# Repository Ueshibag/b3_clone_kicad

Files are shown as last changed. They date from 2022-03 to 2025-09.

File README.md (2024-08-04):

# B3 clone KiCad projects, symbols and footprints libraries

## drawbars

A set of 4 interconnected PCBs controlling 38 potentiometers. The left most PCB houses
an Arduino Nano Every which analog to digital converters are used to collect drawbars
positions and send the corresponding MIDI messages to the B3 emulator software (setBfree) running on a Raspberry Pi.

## keyboards

Scans both Fatar keyboards and sends MIDI messages to setBfree

## percussions_expr_pedal

Scans the percussion control switches and performs analog to digital conversion for the
expression pedal. Signals are routed towards the vibrato_chorus_leslie PCB.

## rpi_extension

This is merely a connection PCB for other boards to connect to the Raspberry PI.

## vibrato_chorus_leslie

Scans the vibrato and chorus switches as well as the Leslie 3-position switch (stop/slow/fast).
Gathers signals from the percussions_expr_pedal PCB. Houses an Arduino Nano Every which sends
MIDI messages to setBfree.

## vibrato_chorus_rotary_switch

A small PCB on which the 6-position rotary switch is soldered. This PCB is connected to the
vibrato_chorus_leslie board.

## volume_reverb_overdrive

This board houses three rotary encoders to control IQaudio PiDAC+ volume, setBfree reverb and overdrive. The overdrive rotary switch embeds a push button to safely power down the Raspberry PI.

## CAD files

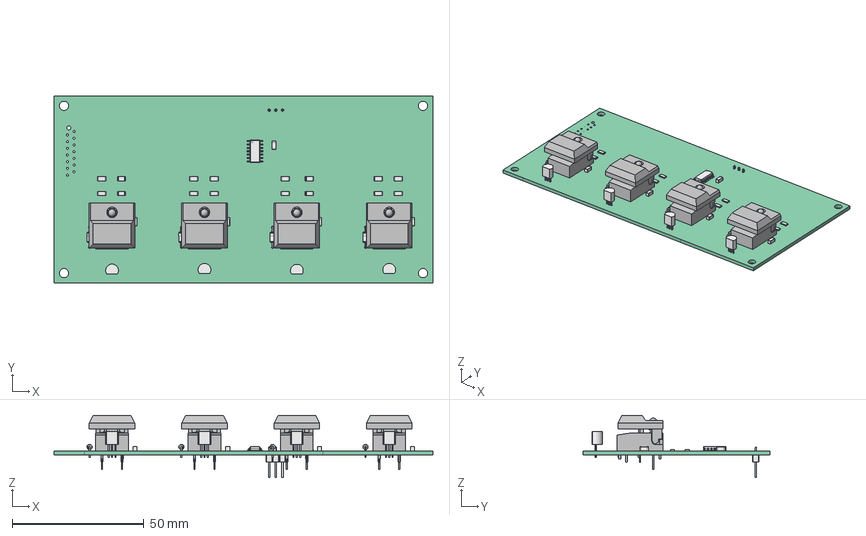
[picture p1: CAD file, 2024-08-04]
percussions_expr_pedal/percussions_expr_pedal.FCStd
143.7 x 71.0 x 23.6 mm
Pcb_b367
R14_R_1206_3216Metric_5984d3bbee4c x 16
C4_C_1206_3216Metric_f569d871501b x 5
Q4_TO-92_Inline_Narrow_949824a83cfa x 4
D3_D_DO-35_SOD27_P7.62mm_Horizontal_7e08c083b87b x 4
U1_SOIC_14_39x87mm_P127mm_67988bc3ad81
J2_PinHeader_1x03_P254mm_Vertical_995c9cfdbebc

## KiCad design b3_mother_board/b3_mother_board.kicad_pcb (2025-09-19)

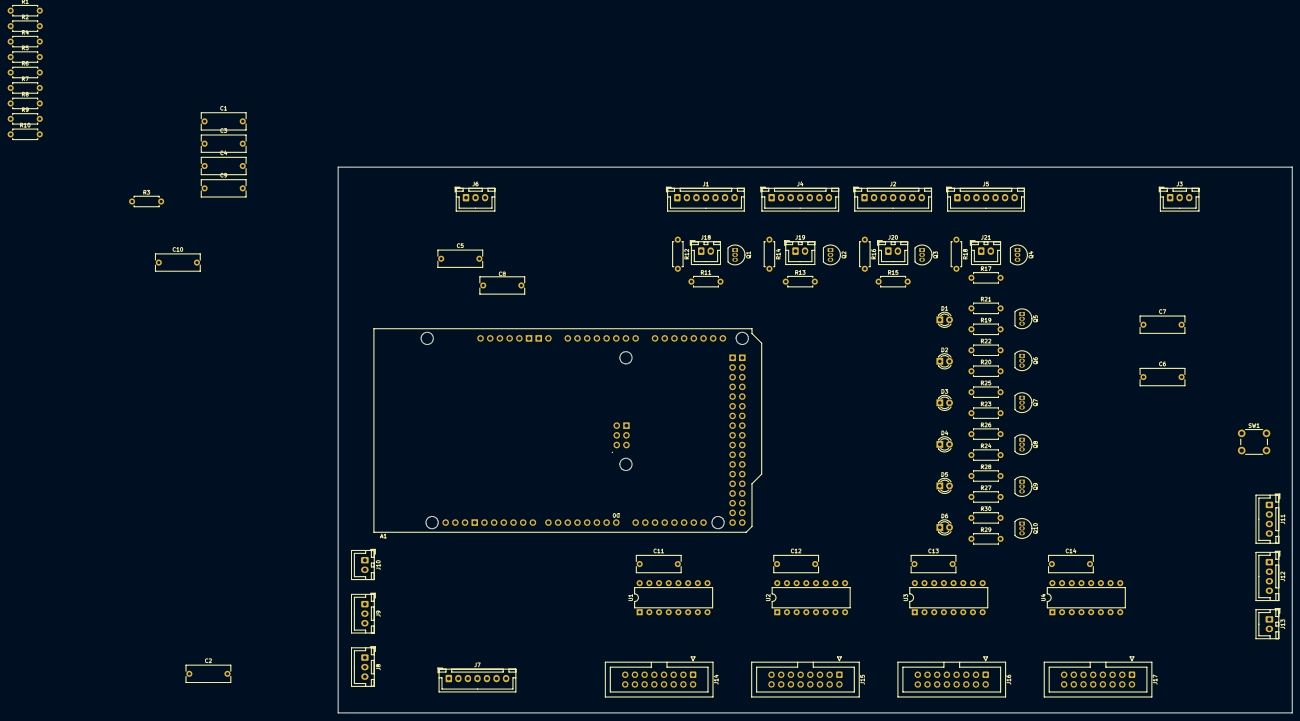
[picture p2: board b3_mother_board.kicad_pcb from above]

Board: 2 copper layers, 250.0 x 143.0 mm, 87 parts (1 on the bottom side), 127 nets, no tracks yet.

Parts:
A1: Arduino_Mega2560_R3_Shield
C1, C2, C3, C4, C5, C6, C7, C8, C9, C10, C11, C12, C13, C14: 100n; C_Rect_L11.5mm_W4.3mm_P10.00mm_MKT
D1: Keyboards; LED_D3.0mm
D2: Vib/Chr; LED_D3.0mm
D3: Drawbars; LED_D3.0mm
D4: Percussions; LED_D3.0mm
D5: Leslie; LED_D3.0mm
D6: Expression Ped.; LED_D3.0mm
J1: Drawbars_1; JST_XH_B7B-XH-A_1x07_P2.50mm_Vertical
J2: Drawbars_3; JST_XH_B7B-XH-A_1x07_P2.50mm_Vertical
J3: Expression Pedal; JST_XH_B3B-XH-A_1x03_P2.50mm_Vertical
J4: Drawbars_2; JST_XH_B7B-XH-A_1x07_P2.50mm_Vertical
J5: Drawbars_4; JST_XH_B7B-XH-A_1x07_P2.50mm_Vertical
J6: Leslie; JST_XH_B3B-XH-A_1x03_P2.50mm_Vertical
J7: V/C Rotary Knob; JST_XH_B7B-XH-A_1x07_P2.50mm_Vertical
J8: Ovrdrv/Vib LEDs; JST_XH_B3B-XH-A_1x03_P2.50mm_Vertical
J9: Ovrdrv/Vib Switches; JST_XH_B3B-XH-A_1x03_P2.50mm_Vertical
J10: Ovrdrv/Vib PWR; JST_XH_B2B-XH-A_1x02_P2.50mm_Vertical
J11: Percussion LEDs; JST_XH_B4B-XH-A_1x04_P2.50mm_Vertical
J12: Percussion Switches; JST_XH_B4B-XH-A_1x04_P2.50mm_Vertical
J13: Percussion PWR; JST_XH_B2B-XH-A_1x02_P2.50mm_Vertical
J14: Upper Keyboard Left; IDC-Header_2x08_P2.54mm_Vertical
J15: Upper Keyboard Right; IDC-Header_2x08_P2.54mm_Vertical
J16: Lower Keyboard Left; IDC-Header_2x08_P2.54mm_Vertical
J17: Lower Keyboard Right; IDC-Header_2x08_P2.54mm_Vertical
J18: Upper A LED; JST_XH_B2B-XH-A_1x02_P2.50mm_Vertical
J19: Upper B LED; JST_XH_B2B-XH-A_1x02_P2.50mm_Vertical
J20: Lower A LED; JST_XH_B2B-XH-A_1x02_P2.50mm_Vertical
J21: Lower B LED; JST_XH_B2B-XH-A_1x02_P2.50mm_Vertical
Q1, Q2, Q3, Q4, Q5, Q6, Q7, Q8, Q9, Q10: BC547; TO-92_Inline
R1, R2: 68K; R_Axial_DIN0207_L6.3mm_D2.5mm_P7.62mm_Horizontal
R3, R4, R5, R6: 2.2K; R_Axial_DIN0207_L6.3mm_D2.5mm_P7.62mm_Horizontal
R7, R8, R9, R10: 100; R_Axial_DIN0207_L6.3mm_D2.5mm_P7.62mm_Horizontal
R11, R13, R15, R17, R19, R20, R23, R24, R27, R29: 2.8K; R_Axial_DIN0207_L6.3mm_D2.5mm_P7.62mm_Horizontal
R12, R14, R16, R18, R21, R22, R25, R26, R28, R30: 220; R_Axial_DIN0207_L6.3mm_D2.5mm_P7.62mm_Horizontal
SW1: Reset; SW_PUSH_6mm_H4.3mm
U1, U2, U3, U4: 4051; DIP-16_W7.62mm

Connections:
+5V: A1.5V1 (5V), A1.5V2 (SPI_5V), A1.5V3 (5V), A1.5V4 (5V), A1.AREF, C11.1, C12.1, C13.1, C14.1, J1.1, J2.1, J3.1, J4.1, J5.1, J6.1, J10.1, J13.1, R1.1, R12.1, R14.1, R16.1, R18.1, R21.1, R22.1, R25.1, R26.1, R28.1, R30.1, U1.16 (VDD), U2.16 (VDD), U3.16 (VDD), U4.16 (VDD)
/C1: A1.D42, J7.2
/C2: A1.D44, J7.4
/C3: A1.D46, J7.6
/DB_A1_ANLG: A1.A0, C1.1, J1.2
/DB_A2_ANLG: A1.A2, C5.1, J4.2
/DB_A3_ANLG: A1.A4, C2.1, J2.2
/DB_A4_ANLG: A1.A6, C6.1, J5.2
/DB_B1_ANLG: A1.A1, C3.1, J1.3
/DB_B2_ANLG: A1.A3, C7.1, J4.3
/DB_B3_ANLG: A1.A5, C4.1, J2.3
/DB_B4_ANLG: A1.A7, C8.1, J5.3
/DB_MUX_A: A1.D47, J1.4, J2.4, J4.4, J5.4
/DB_MUX_B: A1.D48, J1.5, J2.5, J4.5, J5.5
/DB_MUX_C: A1.D49, J1.6, J2.6, J4.6, J5.6
/DWB_LED: A1.D1 (D1/TX0), R23.1
/EXPR_PEDAL_ANLG: A1.A8, C9.1, J3.2
/EXP_LED: A1.D16 (D16/TX2), R29.1
/KBD_LED: A1.D0 (D0/RX0), R19.1
/LESLIE_ANLG: A1.A9, C10.1, J6.2, R1.2, R2.1
/LO_A_LED: A1.D52 (D52_SCK), R15.1
/LO_B_LED: A1.D53 (D53_CS), R17.1
/LSL_LED: A1.D17 (D17/RX2), R27.1
/OVERDRIVE_LED: A1.D30, J8.1
/OVERDRIVE_SWITCH: A1.D27, J9.1
/PERC_DELAY_LED: A1.D39, J11.3
/PERC_DELAY_SWITCH: A1.D35, J12.3
/PERC_HARMONIC_LED: A1.D40, J11.4
/PERC_HARMONIC_SWITCH: A1.D36, J12.4
/PERC_ON_OFF_LED: A1.D37, J11.1
/PERC_ON_OFF_SWITCH: A1.D33, J12.1
/PERC_VOLUME_LED: A1.D38, J11.2
/PERC_VOLUME_SWITCH: A1.D34, J12.2
/PRC_LED: A1.D18 (D18/TX1), R24.1
/T0: A1.D11, J14.2, J15.2, J16.2, J17.2
/T1: A1.D12, J14.4, J15.4, J16.4, J17.4
/T2: A1.D13, J14.6, J15.6, J16.6, J17.6
/T3: A1.D22, J14.8, J15.8, J16.8, J17.8
/T4: A1.D23, J14.10, J15.10, J16.10, J17.10
/T5: A1.D24, J14.12, J15.12, J16.12, J17.12
/T6: A1.D25, J14.14, J15.14, J16.14, J17.14
/T7: A1.D26, J14.16, J15.16, J16.16, J17.16
/UP_A_LED: A1.D50 (D50_MISO), R11.1
/UP_B_LED: A1.D51 (D51_MOSI), R13.1
/V1: A1.D41, J7.1
/V2: A1.D43, J7.3
/V3: A1.D45, J7.5
/VIBRATO_LOWER_LED: A1.D32, J8.3
/VIBRATO_LOWER_SWITCH: A1.D29, J9.3
/VIBRATO_UPPER_LED: A1.D31, J8.2
/VIBRATO_UPPER_SWITCH: A1.D28, J9.2
/VIB_LED: A1.D19 (D19/RX1), R20.1
/keyboards_control_sub/BRA: A1.D7, R7.1
/keyboards_control_sub/BRA0: J14.3, U1.13 (X0)
/keyboards_control_sub/BRA1: J14.7, U1.14 (X1)
/keyboards_control_sub/BRA2: J14.11, U1.15 (X2)
/keyboards_control_sub/BRA3: J14.15, U1.12 (X3)
/keyboards_control_sub/BRA4: J15.3, U1.1 (X4)
/keyboards_control_sub/BRA5: J15.7, U1.5 (X5)
/keyboards_control_sub/BRA6: J15.11, U1.2 (X6)
/keyboards_control_sub/BRA7: J15.15, U1.4 (X7)
/keyboards_control_sub/BRB: A1.D8, R8.1
/keyboards_control_sub/BRB0: J16.3, U3.13 (X0)
/keyboards_control_sub/BRB1: J16.7, U3.14 (X1)
/keyboards_control_sub/BRB2: J16.11, U3.15 (X2)
/keyboards_control_sub/BRB3: J16.15, U3.12 (X3)
/keyboards_control_sub/BRB4: J17.3, U3.1 (X4)
/keyboards_control_sub/BRB5: J17.7, U3.5 (X5)
/keyboards_control_sub/BRB6: J17.11, U3.2 (X6)
/keyboards_control_sub/BRB7: J17.15, U3.4 (X7)
/keyboards_control_sub/KB_MUX_A: A1.D4, U1.11 (A), U2.11 (A), U3.11 (A), U4.11 (A)
/keyboards_control_sub/KB_MUX_B: A1.D5, U1.10 (B), U2.10 (B), U3.10 (B), U4.10 (B)
/keyboards_control_sub/KB_MUX_C: A1.D6, U1.9 (C), U2.9 (C), U3.9 (C), U4.9 (C)
/keyboards_control_sub/MKA: A1.D9, R9.1
/keyboards_control_sub/MKA0: J14.1, U2.13 (X0)
/keyboards_control_sub/MKA1: J14.5, U2.14 (X1)
/keyboards_control_sub/MKA2: J14.9, U2.15 (X2)
/keyboards_control_sub/MKA3: J14.13, U2.12 (X3)
/keyboards_control_sub/MKA4: J15.1, U2.1 (X4)
/keyboards_control_sub/MKA5: J15.5, U2.5 (X5)
/keyboards_control_sub/MKA6: J15.9, U2.2 (X6)
/keyboards_control_sub/MKA7: J15.13, U2.4 (X7)
/keyboards_control_sub/MKB: A1.D10, R10.1
/keyboards_control_sub/MKB0: J16.1, U4.13 (X0)
/keyboards_control_sub/MKB1: J16.5, U4.14 (X1)
/keyboards_control_sub/MKB2: J16.9, U4.15 (X2)
/keyboards_control_sub/MKB3: J16.13, U4.12 (X3)
/keyboards_control_sub/MKB4: J17.1, U4.1 (X4)
/keyboards_control_sub/MKB5: J17.5, U4.5 (X5)
/keyboards_control_sub/MKB6: J17.9, U4.2 (X6)
/keyboards_control_sub/MKB7: J17.13, U4.4 (X7)
GND: A1.GND1 (GND), A1.GND2 (GND), A1.GND3 (GND), A1.GND4 (SPI_GND), A1.GND5 (GND), A1.GND6 (GND), C1.2, C2.2, C3.2, C4.2, C5.2, C6.2, C7.2, C8.2, C9.2, C10.2, C11.2, C12.2, C13.2, C14.2, J1.7, J2.7, J3.3, J4.7, J5.7, J6.3, J7.7, J10.2, J13.2, Q1.3 (E), Q2.3 (E), Q3.3 (E), Q4.3 (E), Q5.3 (E), Q6.3 (E), Q7.3 (E), Q8.3 (E), Q9.3 (E), Q10.3 (E), R2.2, R3.2, R4.2, R5.2, R6.2, SW1.1, U1.6 (Inh), U1.7 (VEE), U1.8 (VSS), U2.6 (Inh), U2.7 (VEE), U2.8 (VSS), U3.6 (Inh), U3.7 (VEE), U3.8 (VSS), U4.6 (Inh), U4.7 (VEE), U4.8 (VSS)
unnamed: A1.RST1 (RESET), SW1.2
unnamed: D1.2 (A), R21.2
unnamed: D1.1 (K), Q5.1 (C)
unnamed: D2.2 (A), R22.2
unnamed: D2.1 (K), Q6.1 (C)
unnamed: D3.2 (A), R25.2
unnamed: D3.1 (K), Q7.1 (C)
unnamed: D4.2 (A), R26.2
unnamed: D4.1 (K), Q8.1 (C)
unnamed: D5.2 (A), R28.2
unnamed: D5.1 (K), Q9.1 (C)
unnamed: D6.2 (A), R30.2
unnamed: D6.1 (K), Q10.1 (C)
unnamed: J18.1, R12.2
unnamed: J18.2, Q1.1 (C)
unnamed: J19.1, R14.2
unnamed: J19.2, Q2.1 (C)
unnamed: J20.1, R16.2
unnamed: J20.2, Q3.1 (C)
unnamed: J21.1, R18.2
unnamed: J21.2, Q4.1 (C)
unnamed: Q1.2 (B), R11.2
unnamed: Q2.2 (B), R13.2
unnamed: Q3.2 (B), R15.2
unnamed: Q4.2 (B), R17.2
unnamed: Q5.2 (B), R19.2
unnamed: Q6.2 (B), R20.2
unnamed: Q7.2 (B), R23.2
unnamed: Q8.2 (B), R24.2
unnamed: Q9.2 (B), R27.2
unnamed: Q10.2 (B), R29.2
unnamed: R3.1, R7.2, U1.3 (X)
unnamed: R4.1, R9.2, U2.3 (X)
unnamed: R5.1, R8.2, U3.3 (X)
unnamed: R6.1, R10.2, U4.3 (X)

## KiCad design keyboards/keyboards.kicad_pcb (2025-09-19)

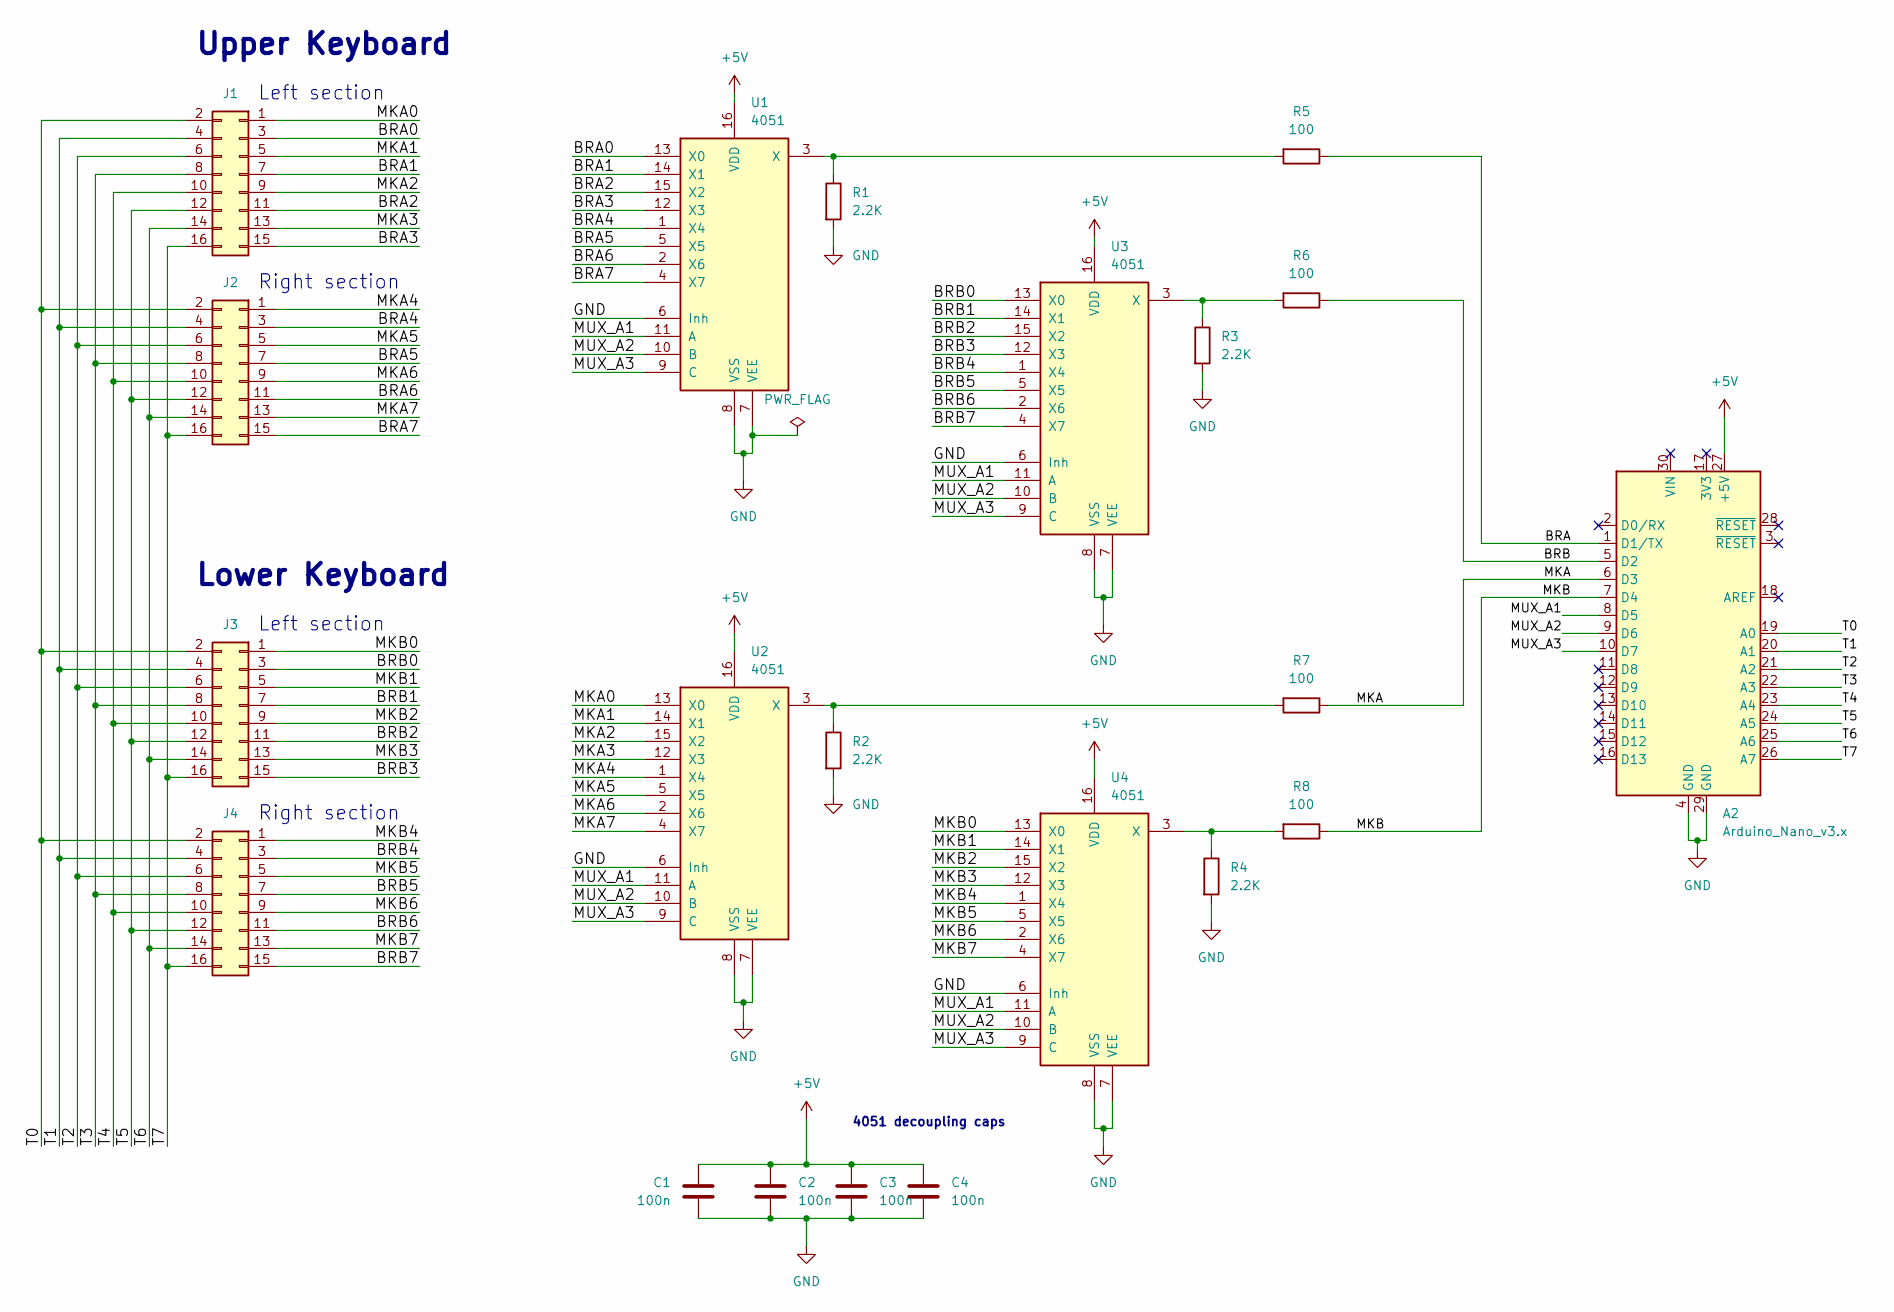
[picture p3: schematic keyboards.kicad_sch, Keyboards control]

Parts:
A2: Arduino_Nano_v3.x; Arduino_Nano
C1, C2, C3, C4: 100n; C_1206_3216Metric_Pad1.33x1.80mm_HandSolder
J1, J2, J3, J4: Conn_02x08_Odd_Even; IDC-Header_2x08_P2.54mm_Vertical
R1, R2, R3, R4: 2.2K; R_1206_3216Metric_Pad1.30x1.75mm_HandSolder
R5, R6, R7, R8: 100; R_1206_3216Metric_Pad1.30x1.75mm_HandSolder
U1, U2, U3, U4: 4051; DIP-16_W7.62mm

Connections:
+5V: A2.27 (+5V), C1.1, C2.1, C3.1, C4.1, U1.16 (VDD), U2.16 (VDD), U3.16 (VDD), U4.16 (VDD)
/BRA: A2.1 (D1/TX), R5.1
/BRA0: J1.3, U1.13 (X0)
/BRA1: J1.7, U1.14 (X1)
/BRA2: J1.11, U1.15 (X2)
/BRA3: J1.15, U1.12 (X3)
/BRA4: J2.3, U1.1 (X4)
/BRA5: J2.7, U1.5 (X5)
/BRA6: J2.11, U1.2 (X6)
/BRA7: J2.15, U1.4 (X7)
/BRB: A2.5 (D2), R6.1
/BRB0: J3.3, U3.13 (X0)
/BRB1: J3.7, U3.14 (X1)
/BRB2: J3.11, U3.15 (X2)
/BRB3: J3.15, U3.12 (X3)
/BRB4: J4.3, U3.1 (X4)
/BRB5: J4.7, U3.5 (X5)
/BRB6: J4.11, U3.2 (X6)
/BRB7: J4.15, U3.4 (X7)
/MKA: A2.6 (D3), R7.1
/MKA0: J1.1, U2.13 (X0)
/MKA1: J1.5, U2.14 (X1)
/MKA2: J1.9, U2.15 (X2)
/MKA3: J1.13, U2.12 (X3)
/MKA4: J2.1, U2.1 (X4)
/MKA5: J2.5, U2.5 (X5)
/MKA6: J2.9, U2.2 (X6)
/MKA7: J2.13, U2.4 (X7)
/MKB: A2.7 (D4), R8.1
/MKB0: J3.1, U4.13 (X0)
/MKB1: J3.5, U4.14 (X1)
/MKB2: J3.9, U4.15 (X2)
/MKB3: J3.13, U4.12 (X3)
/MKB4: J4.1, U4.1 (X4)
/MKB5: J4.5, U4.5 (X5)
/MKB6: J4.9, U4.2 (X6)
/MKB7: J4.13, U4.4 (X7)
/MUX_A1: A2.8 (D5), U1.11 (A), U2.11 (A), U3.11 (A), U4.11 (A)
/MUX_A2: A2.9 (D6), U1.10 (B), U2.10 (B), U3.10 (B), U4.10 (B)
/MUX_A3: A2.10 (D7), U1.9 (C), U2.9 (C), U3.9 (C), U4.9 (C)
/T0: A2.19 (A0), J1.2, J2.2, J3.2, J4.2
/T1: A2.20 (A1), J1.4, J2.4, J3.4, J4.4
/T2: A2.21 (A2), J1.6, J2.6, J3.6, J4.6
/T3: A2.22 (A3), J1.8, J2.8, J3.8, J4.8
/T4: A2.23 (A4), J1.10, J2.10, J3.10, J4.10
/T5: A2.24 (A5), J1.12, J2.12, J3.12, J4.12
/T6: A2.25 (A6), J1.14, J2.14, J3.14, J4.14
/T7: A2.26 (A7), J1.16, J2.16, J3.16, J4.16
GND: A2.4 (GND), A2.29 (GND), C1.2, C2.2, C3.2, C4.2, R1.2, R2.2, R3.2, R4.2, U1.6 (Inh), U1.7 (VEE), U1.8 (VSS), U2.6 (Inh), U2.7 (VEE), U2.8 (VSS), U3.6 (Inh), U3.7 (VEE), U3.8 (VSS), U4.6 (Inh), U4.7 (VEE), U4.8 (VSS)
unnamed: R1.1, R5.2, U1.3 (X)
unnamed: R2.1, R7.2, U2.3 (X)
unnamed: R3.1, R6.2, U3.3 (X)
unnamed: R4.1, R8.2, U4.3 (X)

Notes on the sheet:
Left section
Lower Keyboard
4051 decoupling caps
Upper Keyboard
Right section

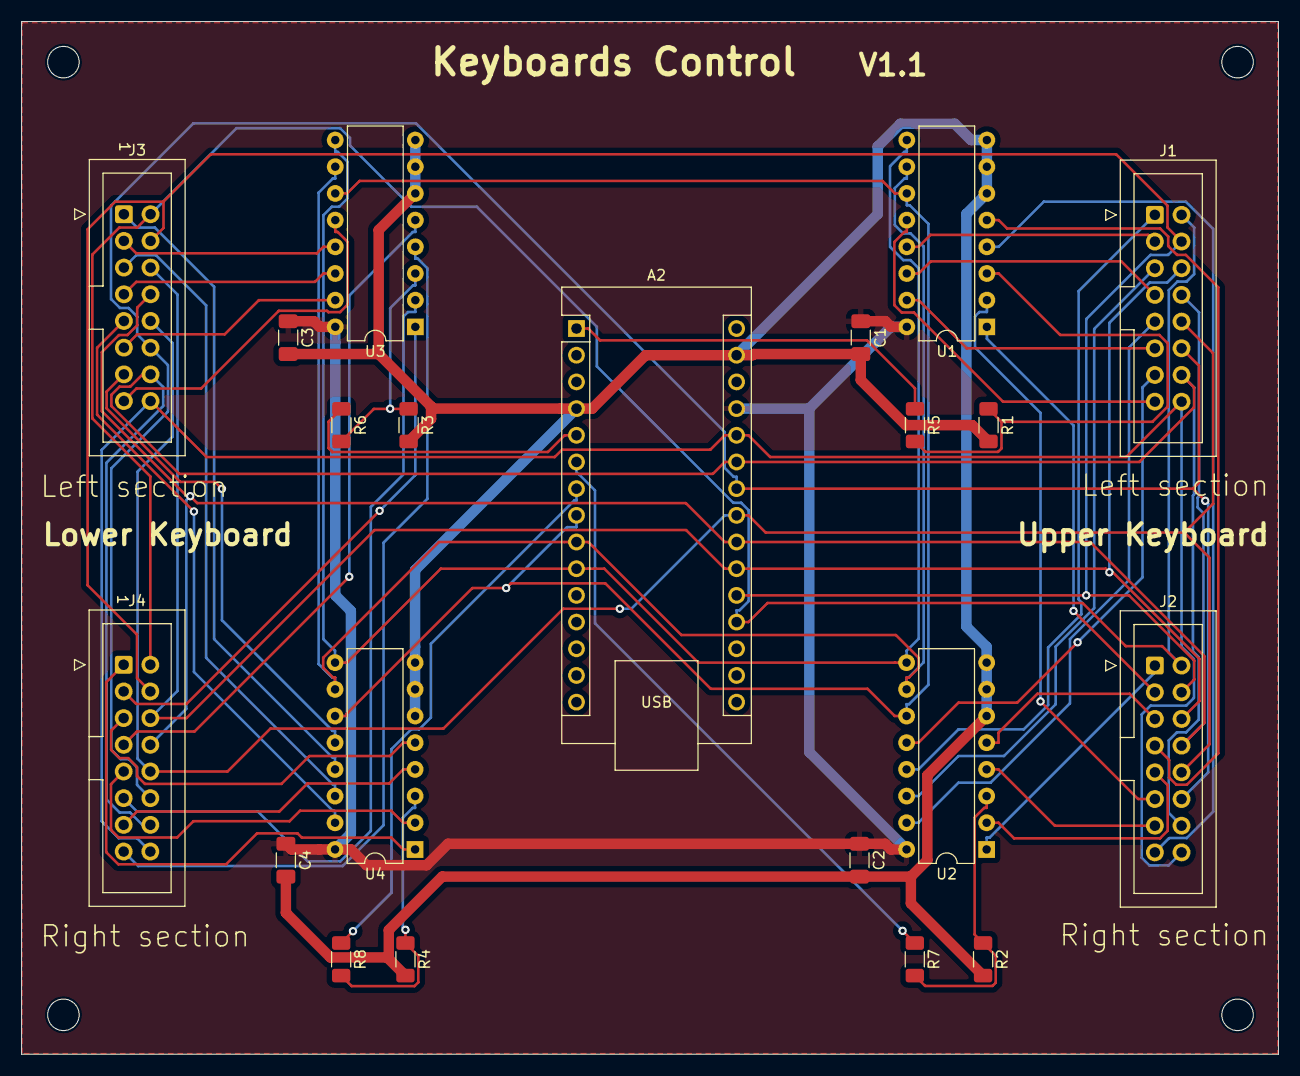
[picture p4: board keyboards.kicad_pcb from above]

Board: 2 copper layers, 119.6 x 98.3 mm, 25 parts (0 on the bottom side), 53 nets.

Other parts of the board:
REF1, REF2, REF3, REF4: MountingHole_3mm

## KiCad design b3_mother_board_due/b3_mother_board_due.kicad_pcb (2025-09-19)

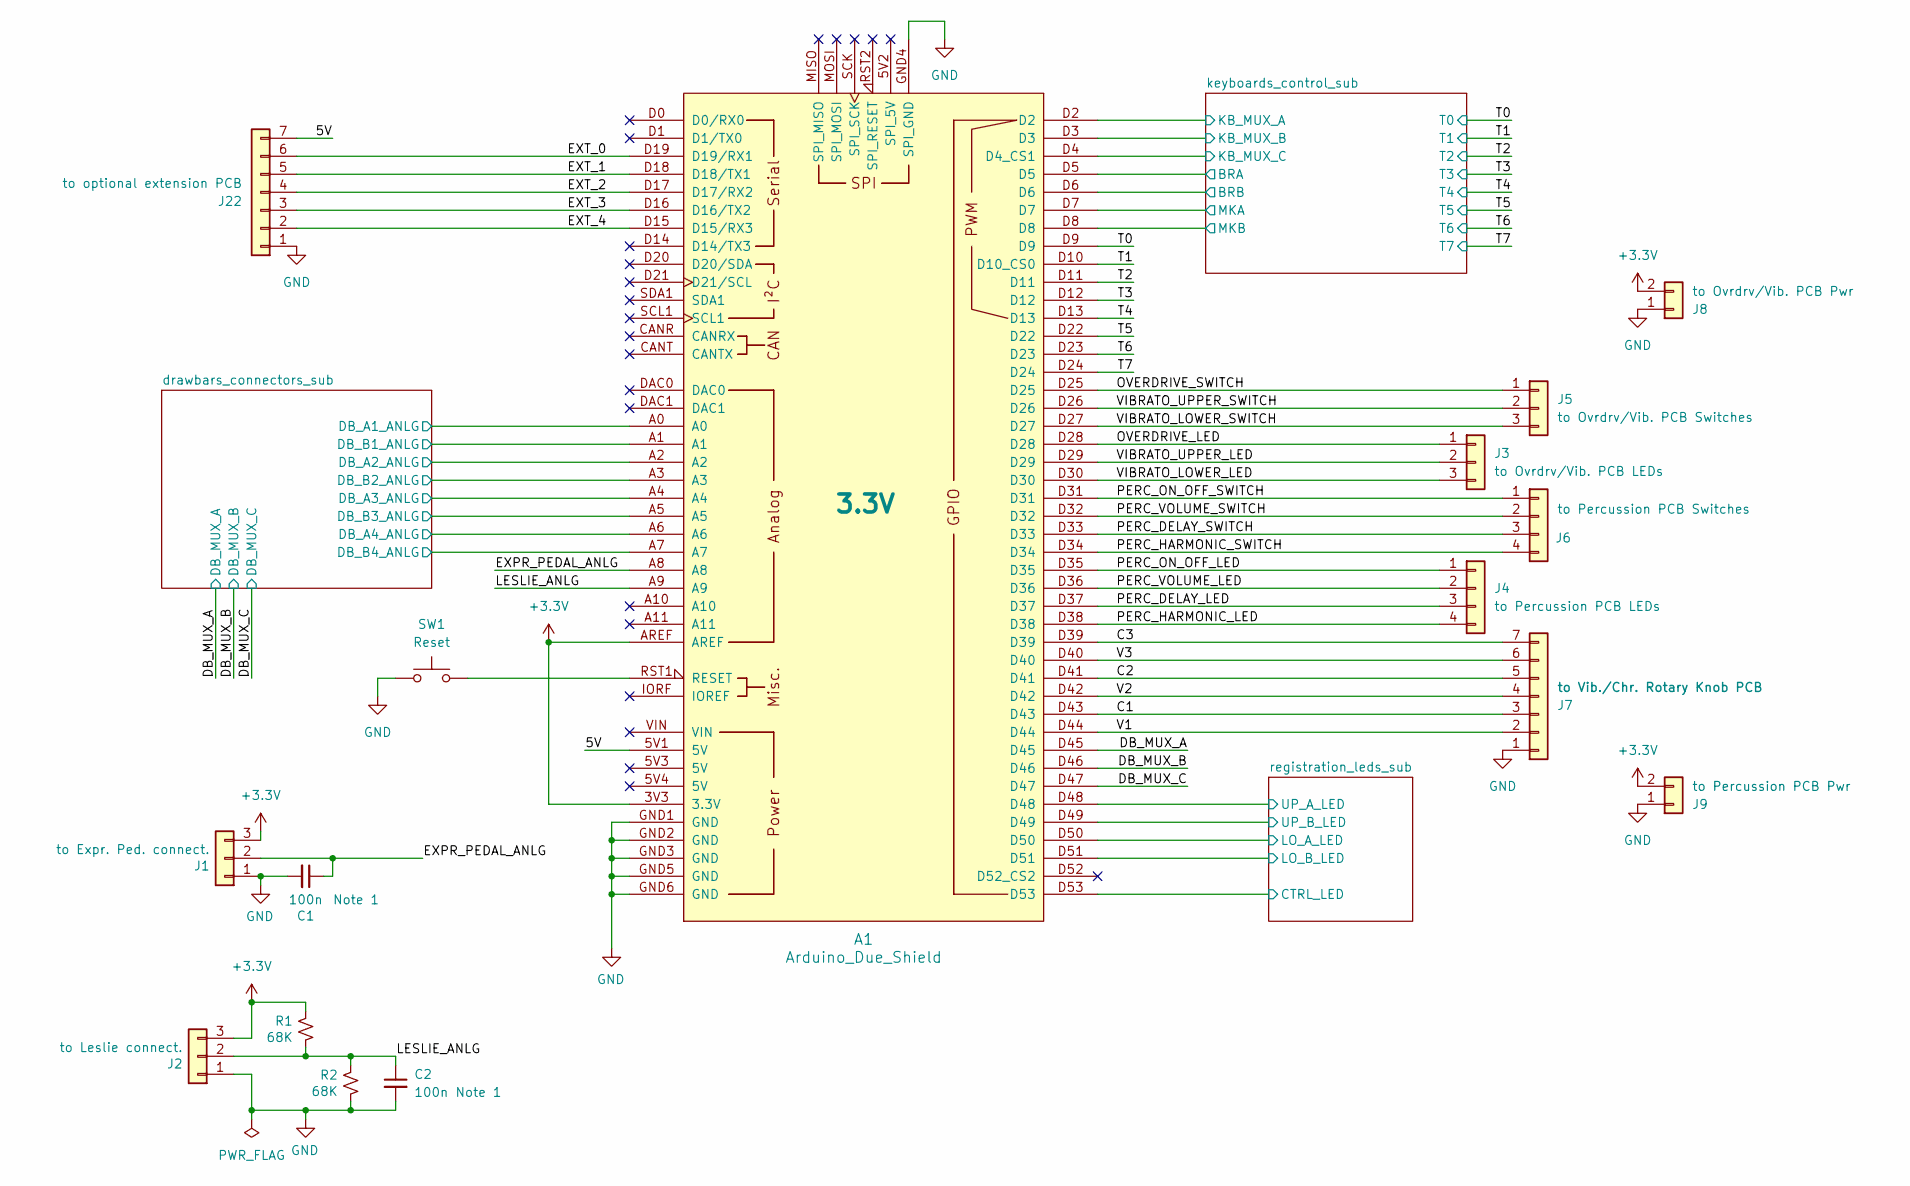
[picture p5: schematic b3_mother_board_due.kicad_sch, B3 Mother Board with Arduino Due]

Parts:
A1: Arduino_Due_Shield; Voltage 3.3V
C1, C2: 100n; C_Rect_L11.5mm_W4.3mm_P10.00mm_MKT
J1: to Expr. Ped. connect.; JST_XH_B3B-XH-A_1x03_P2.50mm_Vertical
J2: to Leslie connect.; JST_XH_B3B-XH-A_1x03_P2.50mm_Vertical
J3: to Ovrdrv/Vib. PCB LEDs; JST_XH_B3B-XH-A_1x03_P2.50mm_Vertical
J4: to Percussion PCB LEDs; JST_XH_B4B-XH-A_1x04_P2.50mm_Vertical
J5: to Ovrdrv/Vib. PCB Switches; JST_XH_B3B-XH-A_1x03_P2.50mm_Vertical
J6: to Percussion PCB Switches; JST_XH_B4B-XH-A_1x04_P2.50mm_Vertical
J7: to Vib./Chr. Rotary Knob PCB; JST_XH_B7B-XH-A_1x07_P2.50mm_Vertical
J8: to Ovrdrv/Vib. PCB Pwr; JST_XH_B2B-XH-A_1x02_P2.50mm_Vertical
J9: to Percussion PCB Pwr; JST_XH_B2B-XH-A_1x02_P2.50mm_Vertical
J22: to optional extension PCB; JST_XH_B7B-XH-A_1x07_P2.50mm_Vertical
R1, R2: 68K; R_Axial_DIN0207_L6.3mm_D2.5mm_P7.62mm_Horizontal
SW1: Reset; SW_PUSH_6mm_H4.3mm

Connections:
+3.3V: A1.3V3 (3.3V), A1.AREF, J1.3, J2.3, J8.2, J9.2, R1.1; also elsewhere on the board
/5V: A1.5V1 (5V), J22.7
/C1: A1.D43, J7.3
/C2: A1.D41, J7.5
/C3: A1.D39, J7.7
/DB_MUX_A: A1.D45; also elsewhere on the board
/DB_MUX_B: A1.D46; also elsewhere on the board
/DB_MUX_C: A1.D47; also elsewhere on the board
/EXPR_PEDAL_ANLG: A1.A8, C1.1, J1.2
/EXT_0: A1.D19 (D19/RX1), J22.6
/EXT_1: A1.D18 (D18/TX1), J22.5
/EXT_2: A1.D17 (D17/RX2), J22.4
/EXT_3: A1.D16 (D16/TX2), J22.3
/EXT_4: A1.D15 (D15/RX3), J22.2
/LESLIE_ANLG: A1.A9, C2.1, J2.2, R1.2, R2.1
/OVERDRIVE_LED: A1.D28, J3.1
/OVERDRIVE_SWITCH: A1.D25, J5.1
/PERC_DELAY_LED: A1.D37, J4.3
/PERC_DELAY_SWITCH: A1.D33, J6.3
/PERC_HARMONIC_LED: A1.D38, J4.4
/PERC_HARMONIC_SWITCH: A1.D34, J6.4
/PERC_ON_OFF_LED: A1.D35, J4.1
/PERC_ON_OFF_SWITCH: A1.D31, J6.1
/PERC_VOLUME_LED: A1.D36, J4.2
/PERC_VOLUME_SWITCH: A1.D32, J6.2
/T0: A1.D9; also elsewhere on the board
/T1: A1.D10 (D10_CS0); also elsewhere on the board
/T2: A1.D11; also elsewhere on the board
/T3: A1.D12; also elsewhere on the board
/T4: A1.D13; also elsewhere on the board
/T5: A1.D22; also elsewhere on the board
/T6: A1.D23; also elsewhere on the board
/T7: A1.D24; also elsewhere on the board
/V1: A1.D44, J7.2
/V2: A1.D42, J7.4
/V3: A1.D40, J7.6
/VIBRATO_LOWER_LED: A1.D30, J3.3
/VIBRATO_LOWER_SWITCH: A1.D27, J5.3
/VIBRATO_UPPER_LED: A1.D29, J3.2
/VIBRATO_UPPER_SWITCH: A1.D26, J5.2
/drawbars_connectors_sub/DB_A1_ANLG: A1.A0; also elsewhere on the board
/drawbars_connectors_sub/DB_A2_ANLG: A1.A2; also elsewhere on the board
/drawbars_connectors_sub/DB_A3_ANLG: A1.A4; also elsewhere on the board
/drawbars_connectors_sub/DB_A4_ANLG: A1.A6; also elsewhere on the board
/drawbars_connectors_sub/DB_B1_ANLG: A1.A1; also elsewhere on the board
/drawbars_connectors_sub/DB_B2_ANLG: A1.A3; also elsewhere on the board
/drawbars_connectors_sub/DB_B3_ANLG: A1.A5; also elsewhere on the board
/drawbars_connectors_sub/DB_B4_ANLG: A1.A7; also elsewhere on the board
/keyboards_control_sub/BRA: A1.D5; also elsewhere on the board
/keyboards_control_sub/BRB: A1.D6; also elsewhere on the board
/keyboards_control_sub/KB_MUX_A: A1.D2; also elsewhere on the board
/keyboards_control_sub/KB_MUX_B: A1.D3; also elsewhere on the board
/keyboards_control_sub/KB_MUX_C: A1.D4 (D4_CS1); also elsewhere on the board
/keyboards_control_sub/MKA: A1.D7; also elsewhere on the board
/keyboards_control_sub/MKB: A1.D8; also elsewhere on the board
/registration_leds_sub/CTRL_LED: A1.D53; also elsewhere on the board
/registration_leds_sub/LO_A_LED: A1.D50; also elsewhere on the board
/registration_leds_sub/LO_B_LED: A1.D51; also elsewhere on the board
/registration_leds_sub/UP_A_LED: A1.D48; also elsewhere on the board
/registration_leds_sub/UP_B_LED: A1.D49; also elsewhere on the board
GND: A1.GND1 (GND), A1.GND2 (GND), A1.GND3 (GND), A1.GND4 (SPI_GND), A1.GND5 (GND), A1.GND6 (GND), C1.2, C2.2, J1.1, J2.1, J7.1, J8.1, J9.1, J22.1, R2.2, SW1.1; also elsewhere on the board
unnamed: A1.RST1 (RESET), SW1.2

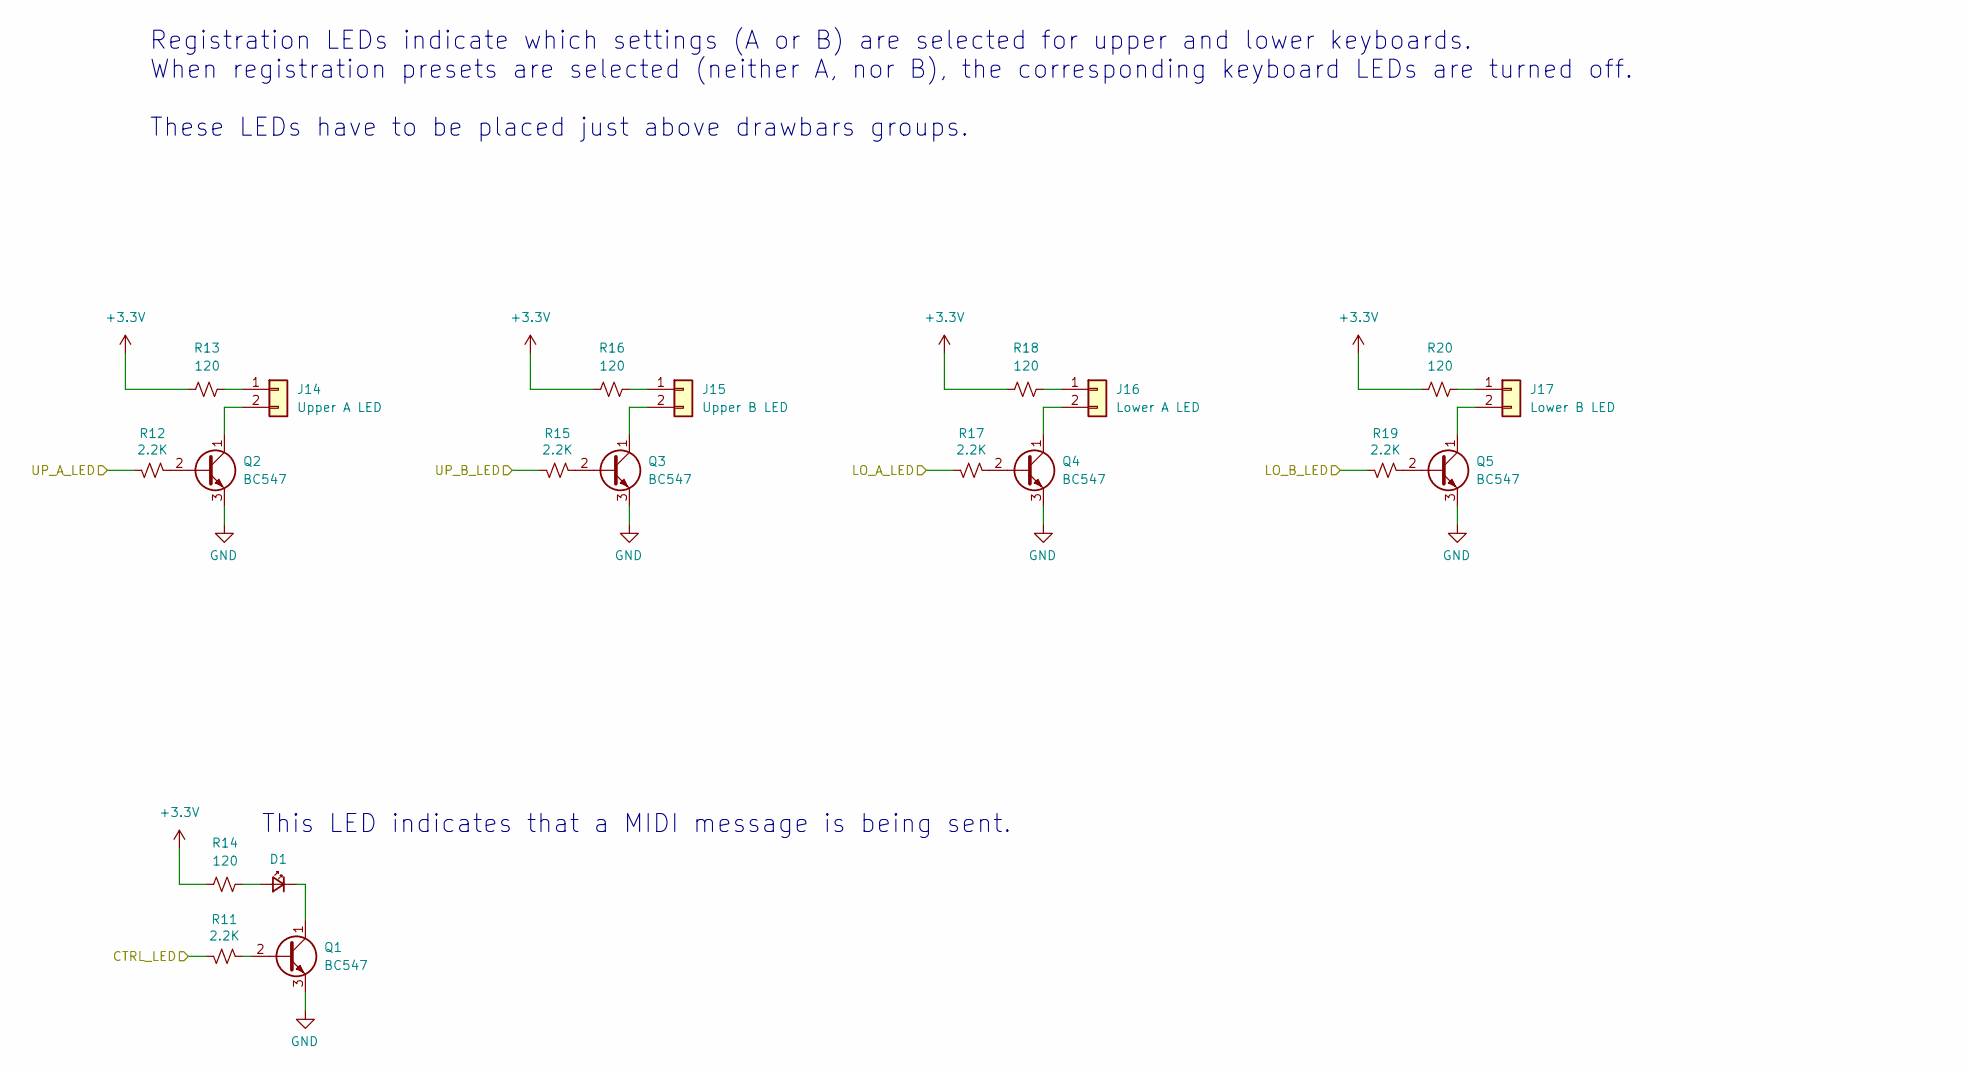
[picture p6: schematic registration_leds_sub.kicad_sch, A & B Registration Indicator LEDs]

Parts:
D1: Keyboards; LED_D3.0mm
J14: Upper A LED; JST_XH_B2B-XH-A_1x02_P2.50mm_Vertical
J15: Upper B LED; JST_XH_B2B-XH-A_1x02_P2.50mm_Vertical
J16: Lower A LED; JST_XH_B2B-XH-A_1x02_P2.50mm_Vertical
J17: Lower B LED; JST_XH_B2B-XH-A_1x02_P2.50mm_Vertical
Q1, Q2, Q3, Q4, Q5: BC547; TO-92_Inline
R11, R12, R15, R17, R19: 2.2K; R_Axial_DIN0207_L6.3mm_D2.5mm_P7.62mm_Horizontal
R13, R14, R16, R18, R20: 120; R_Axial_DIN0207_L6.3mm_D2.5mm_P7.62mm_Horizontal

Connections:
+3.3V: R13.1, R14.1, R16.1, R18.1, R20.1; also elsewhere on the board
/registration_leds_sub/CTRL_LED: R11.1; also elsewhere on the board
/registration_leds_sub/LO_A_LED: R17.1; also elsewhere on the board
/registration_leds_sub/LO_B_LED: R19.1; also elsewhere on the board
/registration_leds_sub/UP_A_LED: R12.1; also elsewhere on the board
/registration_leds_sub/UP_B_LED: R15.1; also elsewhere on the board
GND: Q1.3 (E), Q2.3 (E), Q3.3 (E), Q4.3 (E), Q5.3 (E); also elsewhere on the board
unnamed: D1.2 (A), R14.2
unnamed: D1.1 (K), Q1.1 (C)
unnamed: J14.1, R13.2
unnamed: J14.2, Q2.1 (C)
unnamed: J15.1, R16.2
unnamed: J15.2, Q3.1 (C)
unnamed: J16.1, R18.2
unnamed: J16.2, Q4.1 (C)
unnamed: J17.1, R20.2
unnamed: J17.2, Q5.1 (C)
unnamed: Q1.2 (B), R11.2
unnamed: Q2.2 (B), R12.2
unnamed: Q3.2 (B), R15.2
unnamed: Q4.2 (B), R17.2
unnamed: Q5.2 (B), R19.2

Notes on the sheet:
Registration LEDs indicate which settings (A or B) are selected for upper and lower keyboards. When registration presets are selected (neither A, nor B), the corresponding keyboard LEDs are turned off. These LEDs have to be placed just above drawbars groups.
This LED indicates that a MIDI message is being sent.

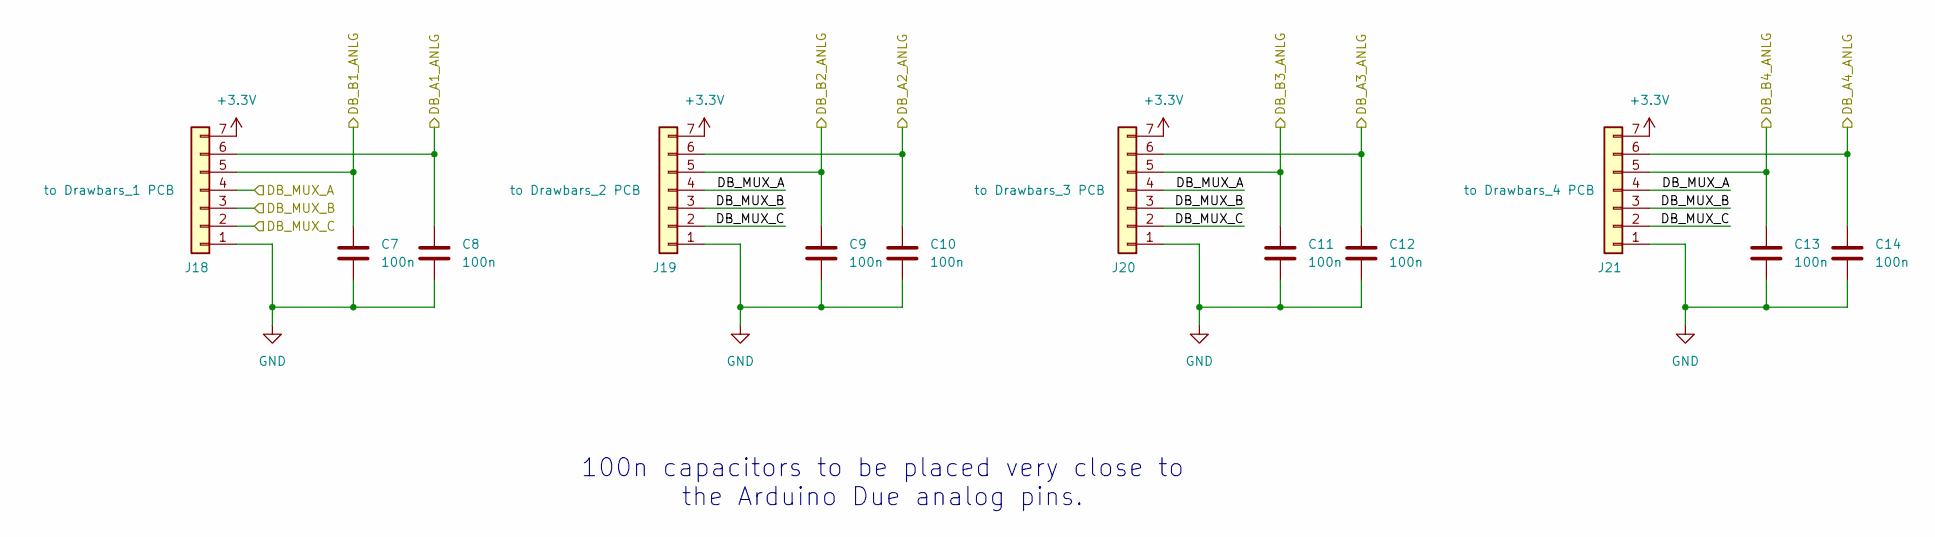
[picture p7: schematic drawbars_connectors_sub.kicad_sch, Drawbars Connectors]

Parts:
C7, C8, C9, C10, C11, C12, C13, C14: 100n; C_Rect_L11.5mm_W4.3mm_P10.00mm_MKT
J18: to Drawbars_1 PCB; JST_XH_B7B-XH-A_1x07_P2.50mm_Vertical
J19: to Drawbars_2 PCB; JST_XH_B7B-XH-A_1x07_P2.50mm_Vertical
J20: to Drawbars_3 PCB; JST_XH_B7B-XH-A_1x07_P2.50mm_Vertical
J21: to Drawbars_4 PCB; JST_XH_B7B-XH-A_1x07_P2.50mm_Vertical

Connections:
+3.3V: J18.7, J19.7, J20.7, J21.7; also elsewhere on the board
/DB_MUX_A: J18.4, J19.4, J20.4, J21.4; also elsewhere on the board
/DB_MUX_B: J18.3, J19.3, J20.3, J21.3; also elsewhere on the board
/DB_MUX_C: J18.2, J19.2, J20.2, J21.2; also elsewhere on the board
/drawbars_connectors_sub/DB_A1_ANLG: C8.1, J18.6; also elsewhere on the board
/drawbars_connectors_sub/DB_A2_ANLG: C10.1, J19.6; also elsewhere on the board
/drawbars_connectors_sub/DB_A3_ANLG: C12.1, J20.6; also elsewhere on the board
/drawbars_connectors_sub/DB_A4_ANLG: C14.1, J21.6; also elsewhere on the board
/drawbars_connectors_sub/DB_B1_ANLG: C7.1, J18.5; also elsewhere on the board
/drawbars_connectors_sub/DB_B2_ANLG: C9.1, J19.5; also elsewhere on the board
/drawbars_connectors_sub/DB_B3_ANLG: C11.1, J20.5; also elsewhere on the board
/drawbars_connectors_sub/DB_B4_ANLG: C13.1, J21.5; also elsewhere on the board
GND: C7.2, C8.2, C9.2, C10.2, C11.2, C12.2, C13.2, C14.2, J18.1, J19.1, J20.1, J21.1; also elsewhere on the board

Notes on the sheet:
100n capacitors to be placed very close to the Arduino Due analog pins.

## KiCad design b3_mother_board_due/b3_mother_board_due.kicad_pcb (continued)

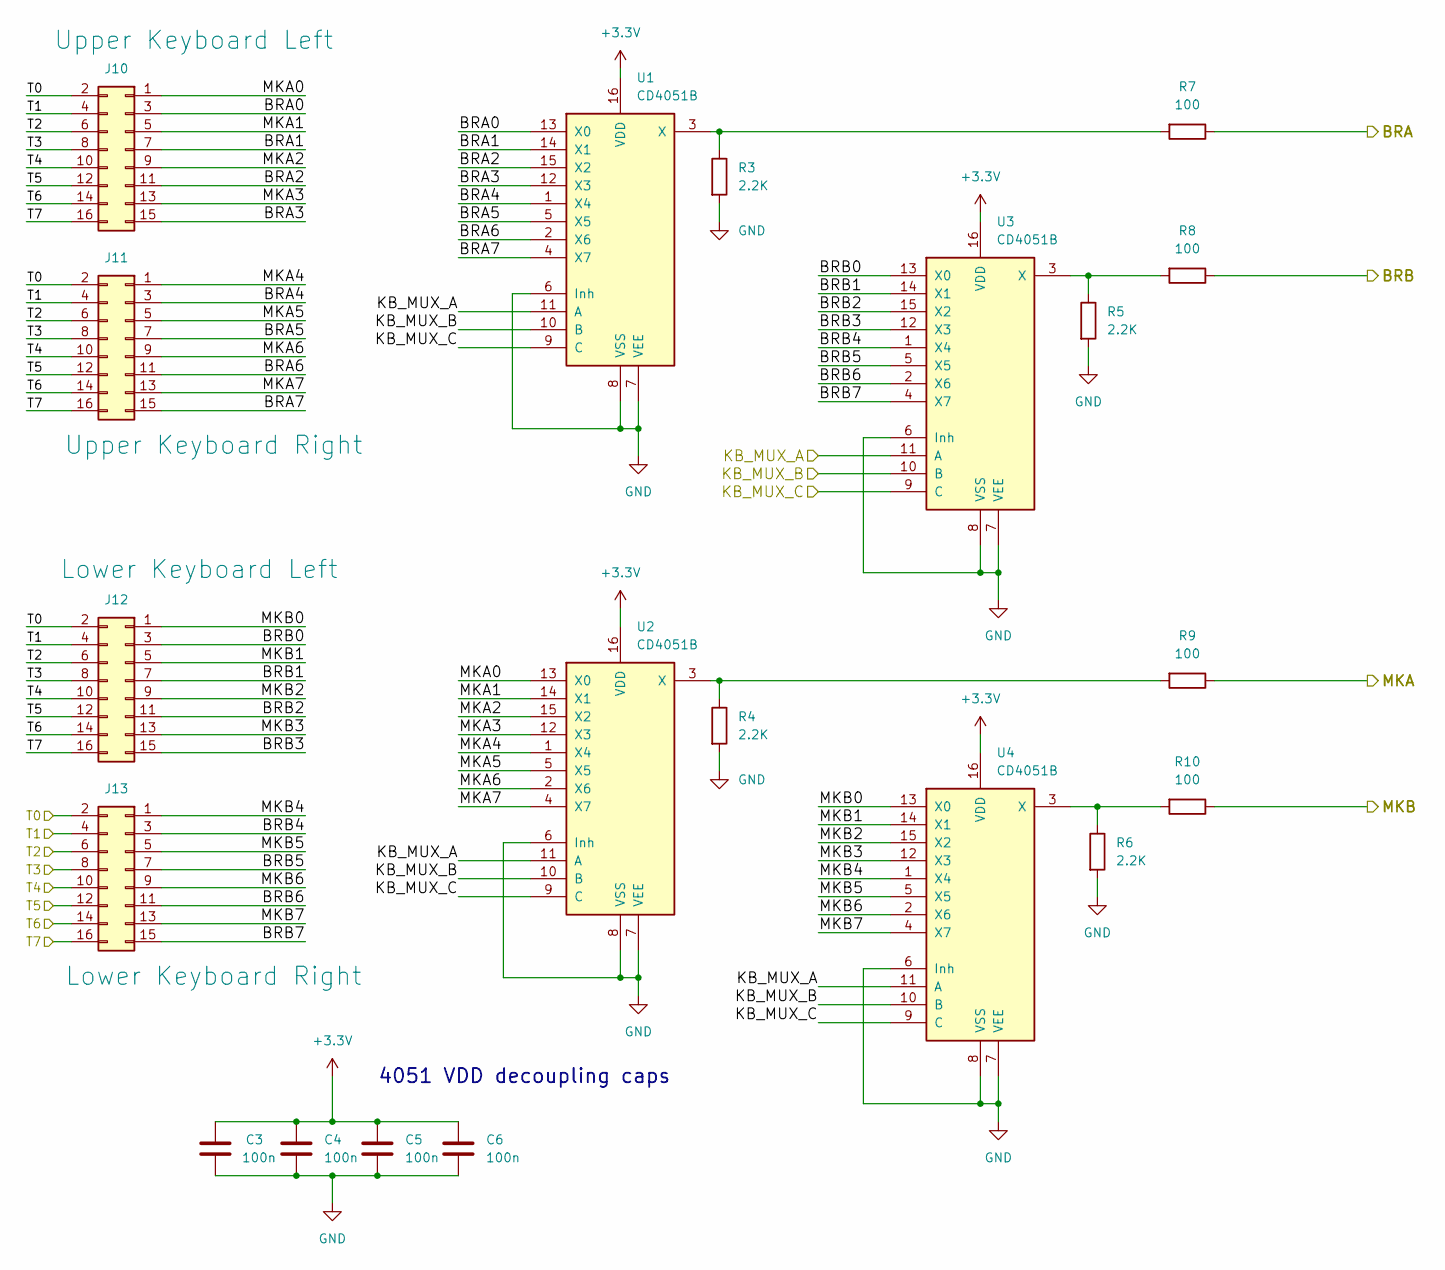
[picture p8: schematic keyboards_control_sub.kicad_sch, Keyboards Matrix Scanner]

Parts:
C3, C4, C5, C6: 100n; C_Rect_L11.5mm_W4.3mm_P10.00mm_MKT
J10: Upper Keyboard Left; IDC-Header_2x08_P2.54mm_Vertical
J11: Upper Keyboard Right; IDC-Header_2x08_P2.54mm_Vertical
J12: Lower Keyboard Left; IDC-Header_2x08_P2.54mm_Vertical
J13: Lower Keyboard Right; IDC-Header_2x08_P2.54mm_Vertical
R3, R4, R5, R6: 2.2K; R_Axial_DIN0207_L6.3mm_D2.5mm_P7.62mm_Horizontal
R7, R8, R9, R10: 100; R_Axial_DIN0207_L6.3mm_D2.5mm_P7.62mm_Horizontal
U1, U2, U3, U4: CD4051B; DIP-16_W7.62mm

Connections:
+3.3V: C3.1, C4.1, C5.1, C6.1, U1.16 (VDD), U2.16 (VDD), U3.16 (VDD), U4.16 (VDD); also elsewhere on the board
/T0: J10.2, J11.2, J12.2, J13.2; also elsewhere on the board
/T1: J10.4, J11.4, J12.4, J13.4; also elsewhere on the board
/T2: J10.6, J11.6, J12.6, J13.6; also elsewhere on the board
/T3: J10.8, J11.8, J12.8, J13.8; also elsewhere on the board
/T4: J10.10, J11.10, J12.10, J13.10; also elsewhere on the board
/T5: J10.12, J11.12, J12.12, J13.12; also elsewhere on the board
/T6: J10.14, J11.14, J12.14, J13.14; also elsewhere on the board
/T7: J10.16, J11.16, J12.16, J13.16; also elsewhere on the board
/keyboards_control_sub/BRA: R7.1; also elsewhere on the board
/keyboards_control_sub/BRA0: J10.3, U1.13 (X0)
/keyboards_control_sub/BRA1: J10.7, U1.14 (X1)
/keyboards_control_sub/BRA2: J10.11, U1.15 (X2)
/keyboards_control_sub/BRA3: J10.15, U1.12 (X3)
/keyboards_control_sub/BRA4: J11.3, U1.1 (X4)
/keyboards_control_sub/BRA5: J11.7, U1.5 (X5)
/keyboards_control_sub/BRA6: J11.11, U1.2 (X6)
/keyboards_control_sub/BRA7: J11.15, U1.4 (X7)
/keyboards_control_sub/BRB: R8.1; also elsewhere on the board
/keyboards_control_sub/BRB0: J12.3, U3.13 (X0)
/keyboards_control_sub/BRB1: J12.7, U3.14 (X1)
/keyboards_control_sub/BRB2: J12.11, U3.15 (X2)
/keyboards_control_sub/BRB3: J12.15, U3.12 (X3)
/keyboards_control_sub/BRB4: J13.3, U3.1 (X4)
/keyboards_control_sub/BRB5: J13.7, U3.5 (X5)
/keyboards_control_sub/BRB6: J13.11, U3.2 (X6)
/keyboards_control_sub/BRB7: J13.15, U3.4 (X7)
/keyboards_control_sub/KB_MUX_A: U1.11 (A), U2.11 (A), U3.11 (A), U4.11 (A); also elsewhere on the board
/keyboards_control_sub/KB_MUX_B: U1.10 (B), U2.10 (B), U3.10 (B), U4.10 (B); also elsewhere on the board
/keyboards_control_sub/KB_MUX_C: U1.9 (C), U2.9 (C), U3.9 (C), U4.9 (C); also elsewhere on the board
/keyboards_control_sub/MKA: R9.1; also elsewhere on the board
/keyboards_control_sub/MKA0: J10.1, U2.13 (X0)
/keyboards_control_sub/MKA1: J10.5, U2.14 (X1)
/keyboards_control_sub/MKA2: J10.9, U2.15 (X2)
/keyboards_control_sub/MKA3: J10.13, U2.12 (X3)
/keyboards_control_sub/MKA4: J11.1, U2.1 (X4)
/keyboards_control_sub/MKA5: J11.5, U2.5 (X5)
/keyboards_control_sub/MKA6: J11.9, U2.2 (X6)
/keyboards_control_sub/MKA7: J11.13, U2.4 (X7)
/keyboards_control_sub/MKB: R10.1; also elsewhere on the board
/keyboards_control_sub/MKB0: J12.1, U4.13 (X0)
/keyboards_control_sub/MKB1: J12.5, U4.14 (X1)
/keyboards_control_sub/MKB2: J12.9, U4.15 (X2)
/keyboards_control_sub/MKB3: J12.13, U4.12 (X3)
/keyboards_control_sub/MKB4: J13.1, U4.1 (X4)
/keyboards_control_sub/MKB5: J13.5, U4.5 (X5)
/keyboards_control_sub/MKB6: J13.9, U4.2 (X6)
/keyboards_control_sub/MKB7: J13.13, U4.4 (X7)
GND: C3.2, C4.2, C5.2, C6.2, R3.2, R4.2, R5.2, R6.2, U1.6 (Inh), U1.7 (VEE), U1.8 (VSS), U2.6 (Inh), U2.7 (VEE), U2.8 (VSS), U3.6 (Inh), U3.7 (VEE), U3.8 (VSS), U4.6 (Inh), U4.7 (VEE), U4.8 (VSS); also elsewhere on the board
unnamed: R3.1, R7.2, U1.3 (X)
unnamed: R4.1, R9.2, U2.3 (X)
unnamed: R5.1, R8.2, U3.3 (X)
unnamed: R6.1, R10.2, U4.3 (X)

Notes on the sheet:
4051 VDD decoupling caps

Board: 2 copper layers, 68 parts (0 on the bottom side), 113 nets, no tracks yet.

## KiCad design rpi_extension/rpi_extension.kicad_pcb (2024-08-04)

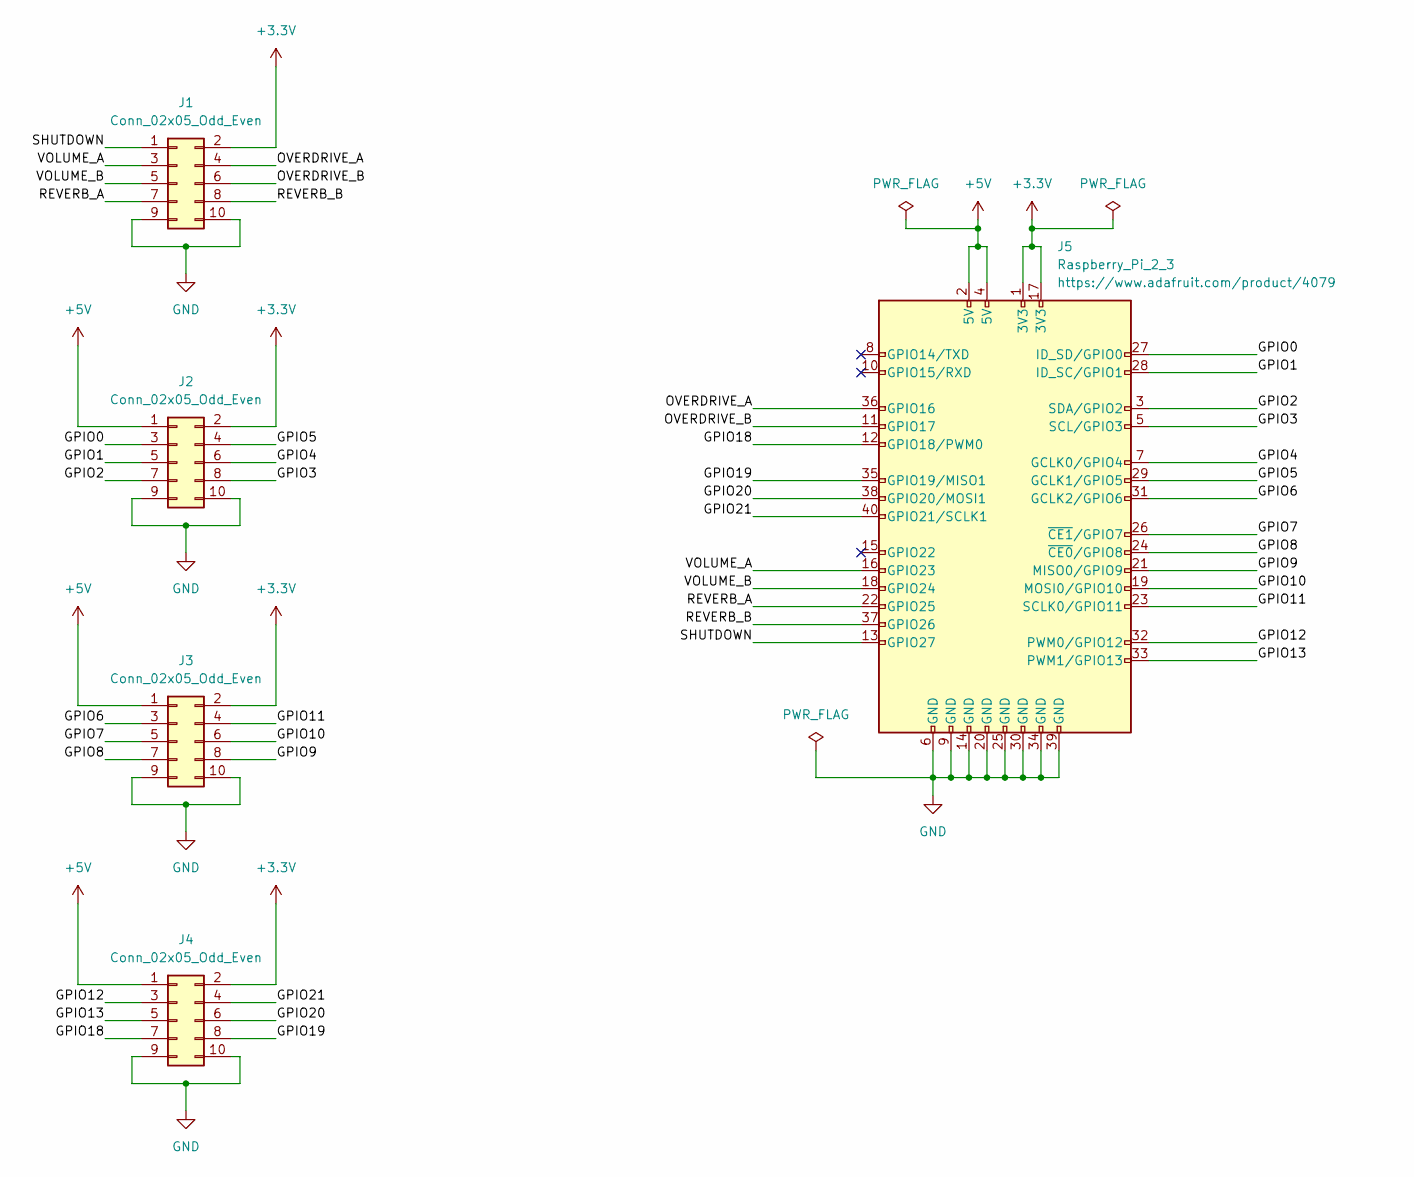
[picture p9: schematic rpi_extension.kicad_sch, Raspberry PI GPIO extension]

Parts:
J1, J2, J3, J4: Conn_02x05_Odd_Even; IDC-Header_2x05_P2.54mm_Horizontal
J5: Raspberry_Pi_2_3; PinSocket_2x20_P2.54mm_Vertical

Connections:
+3.3V: J1.2, J2.2, J3.2, J4.2, J5.1 (3V3), J5.17 (3V3)
+5V: J2.1, J3.1, J4.1, J5.2 (5V), J5.4 (5V)
/GPIO0: J2.3, J5.27 (ID_SD/GPIO0)
/GPIO1: J2.5, J5.28 (ID_SC/GPIO1)
/GPIO2: J2.7, J5.3 (SDA/GPIO2)
/GPIO3: J2.8, J5.5 (SCL/GPIO3)
/GPIO4: J2.6, J5.7 (GCLK0/GPIO4)
/GPIO5: J2.4, J5.29 (GCLK1/GPIO5)
/GPIO6: J3.3, J5.31 (GCLK2/GPIO6)
/GPIO7: J3.5, J5.26 (~CE1/GPIO7)
/GPIO8: J3.7, J5.24 (~CE0/GPIO8)
/GPIO9: J3.8, J5.21 (MISO0/GPIO9)
/GPIO10: J3.6, J5.19 (MOSI0/GPIO10)
/GPIO11: J3.4, J5.23 (SCLK0/GPIO11)
/GPIO12: J4.3, J5.32 (PWM0/GPIO12)
/GPIO13: J4.5, J5.33 (PWM1/GPIO13)
/GPIO18: J4.7, J5.12 (GPIO18/PWM0)
/GPIO19: J4.8, J5.35 (GPIO19/MISO1)
/GPIO20: J4.6, J5.38 (GPIO20/MOSI1)
/GPIO21: J4.4, J5.40 (GPIO21/SCLK1)
/OVERDRIVE_A: J1.4, J5.36 (GPIO16)
/OVERDRIVE_B: J1.6, J5.11 (GPIO17)
/REVERB_A: J1.7, J5.22 (GPIO25)
/REVERB_B: J1.8, J5.37 (GPIO26)
/SHUTDOWN: J1.1, J5.13 (GPIO27)
/VOLUME_A: J1.3, J5.16 (GPIO23)
/VOLUME_B: J1.5, J5.18 (GPIO24)
GND: J1.9, J1.10, J2.9, J2.10, J3.9, J3.10, J4.9, J4.10, J5.6 (GND), J5.9 (GND), J5.14 (GND), J5.20 (GND), J5.25 (GND), J5.30 (GND), J5.34 (GND), J5.39 (GND)

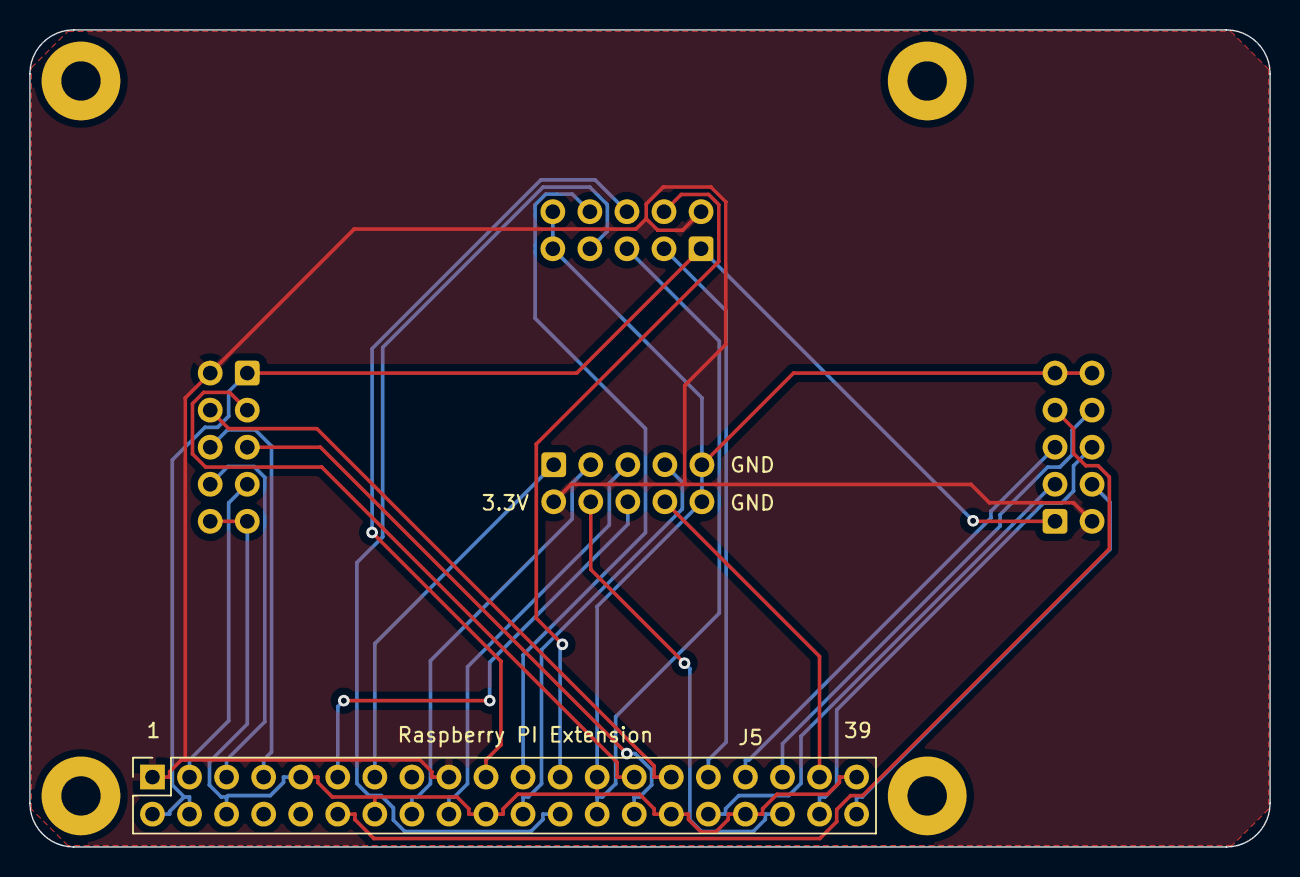
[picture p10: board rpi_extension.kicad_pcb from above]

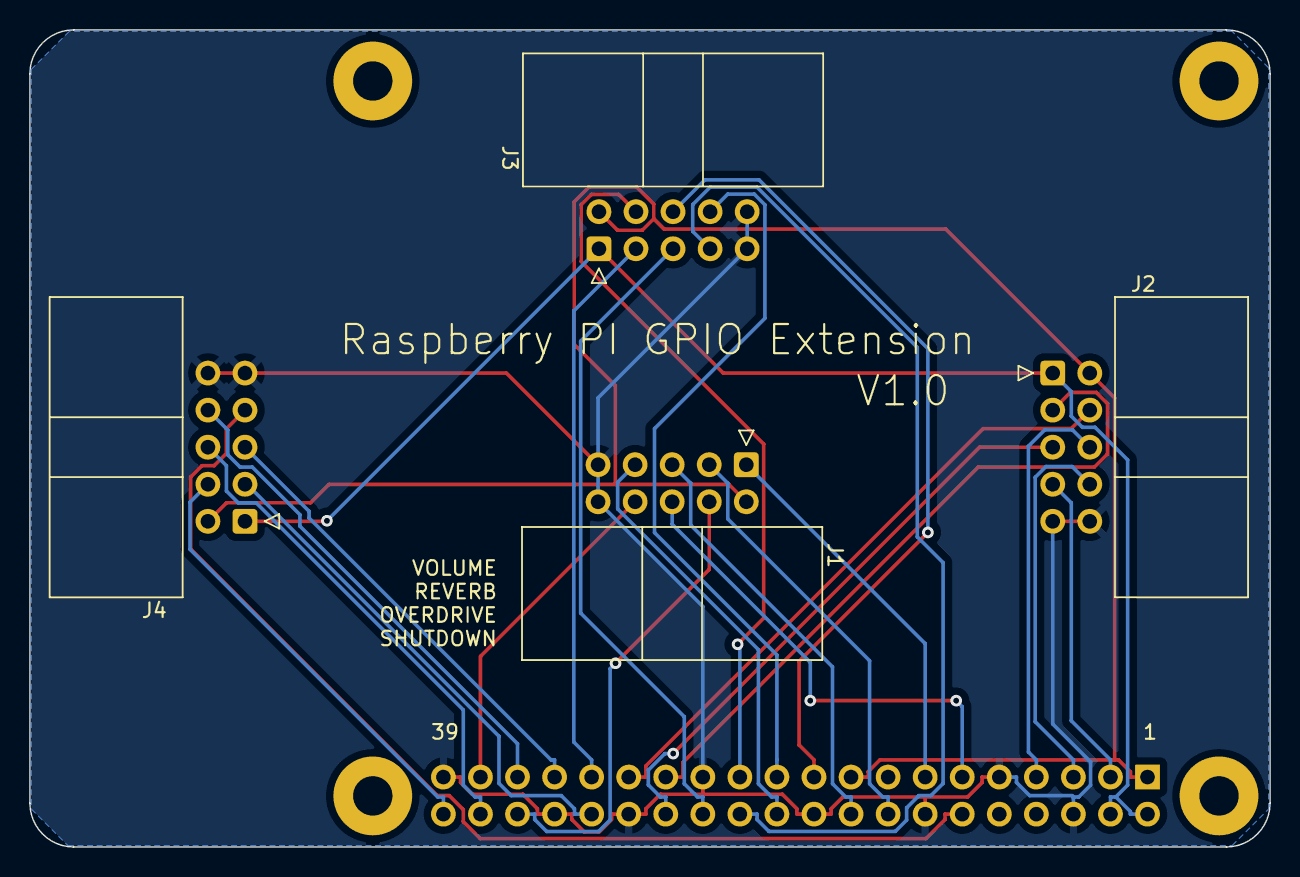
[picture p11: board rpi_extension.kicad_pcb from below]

Board: 2 copper layers, 85.0 x 56.0 mm, 9 parts (4 on the bottom side), 28 nets.

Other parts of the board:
REF1, REF2, REF3, REF4: MountingHole_2.7mm_Pad

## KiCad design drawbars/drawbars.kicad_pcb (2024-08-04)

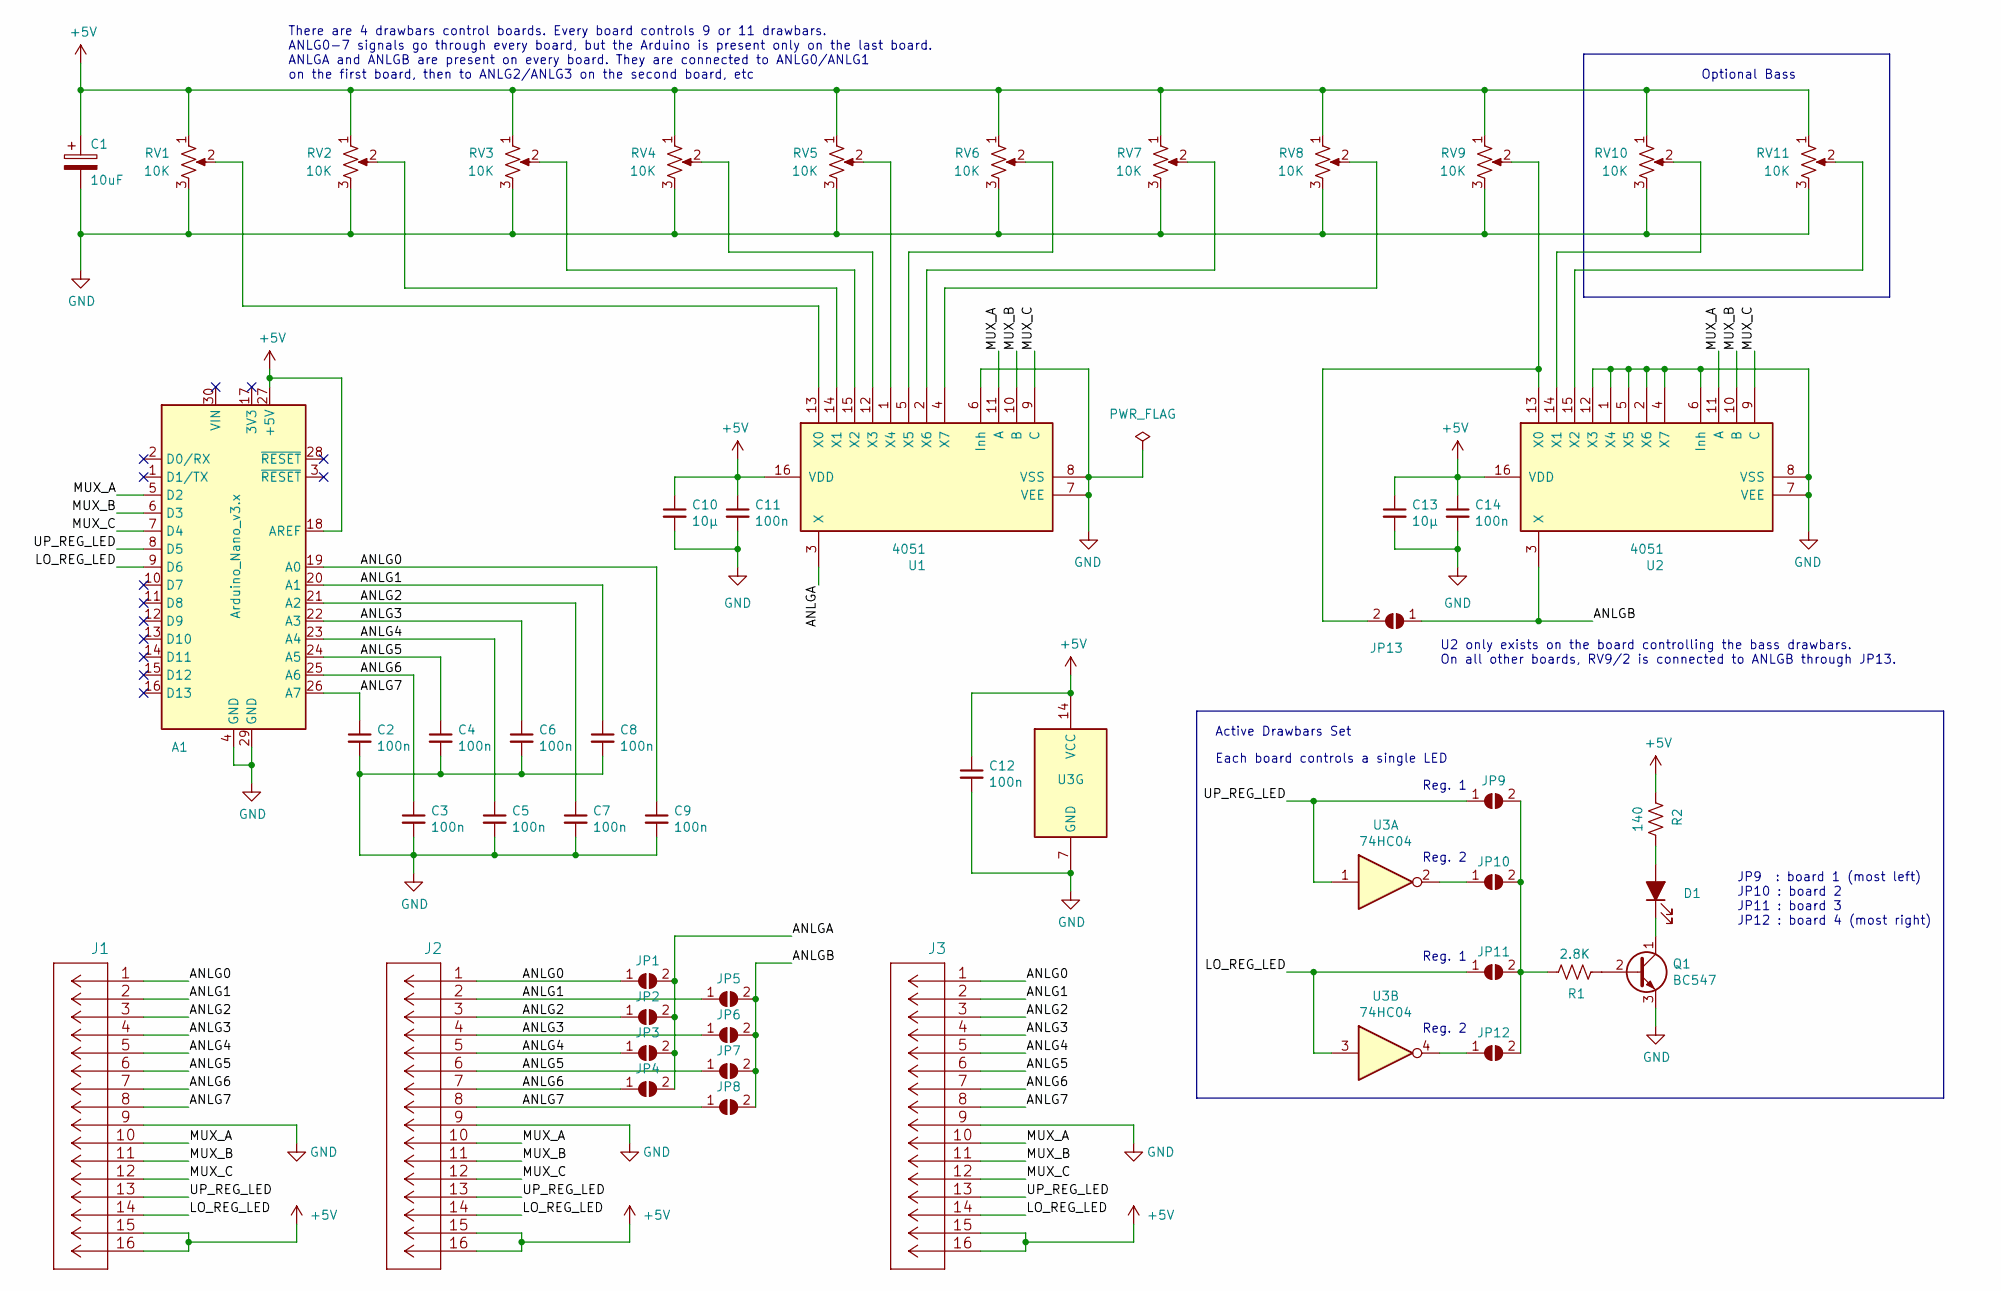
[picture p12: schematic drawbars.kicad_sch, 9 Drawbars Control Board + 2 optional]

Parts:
A1: Arduino_Nano_v3.x; Arduino_Nano
C1: 10uF; CP_Axial_L10.0mm_D4.5mm_P15.00mm_Horizontal
C2, C3, C4, C5, C6, C7, C8, C9, C11, C12, C14: 100n; C_1206_3216Metric_Pad1.33x1.80mm_HandSolder
C10, C13: 10µ; C_1206_3216Metric_Pad1.33x1.80mm_HandSolder
D1: LED_Filled; LED_D3.0mm_FlatTop
J1, J2, J3: 8-215079-6; MicroMatch_2x08_P1.27mm_Vertical
JP1, JP2, JP3, JP4, JP5, JP6, JP7, JP8, JP9, JP10, JP11, JP12, JP13: SolderJumper_2_Open; SolderJumper-2_P1.3mm_Open_RoundedPad1.0x1.5mm
Q1: BC547; TO-92_Inline
R1: 2.8K; R_1206_3216Metric_Pad1.30x1.75mm_HandSolder
R2: 140; R_1206_3216Metric_Pad1.30x1.75mm_HandSolder
RV1, RV2, RV3, RV4, RV5, RV6, RV7, RV8, RV9, RV10, RV11: 10K; Drawbar_Potentiometer
U1, U2: 4051; DIP-16_W7.62mm
U3: 74HC04; DIP-14_W7.62mm

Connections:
+5V: A1.18 (AREF), A1.27 (+5V), C1.1, C10.1, C11.1, C12.1, C13.1, C14.1, J1.15, J1.16, J2.15, J2.16, J3.15, J3.16, R2.2, RV1.1, RV2.1, RV3.1, RV4.1, RV5.1, RV6.1, RV7.1, RV8.1, RV9.1, RV10.1, RV11.1, U1.16 (VDD), U2.16 (VDD), U3.14 (VCC)
/ANLG0: A1.19 (A0), C9.1, J1.1, J2.1, J3.1, JP1.1 (A)
/ANLG1: A1.20 (A1), C8.1, J1.2, J2.2, J3.2, JP5.1 (A)
/ANLG2: A1.21 (A2), C7.1, J1.3, J2.3, J3.3, JP2.1 (A)
/ANLG3: A1.22 (A3), C6.1, J1.4, J2.4, J3.4, JP6.1 (A)
/ANLG4: A1.23 (A4), C5.1, J1.5, J2.5, J3.5, JP3.1 (A)
/ANLG5: A1.24 (A5), C4.1, J1.6, J2.6, J3.6, JP7.1 (A)
/ANLG6: A1.25 (A6), C3.1, J1.7, J2.7, J3.7, JP4.1 (A)
/ANLG7: A1.26 (A7), C2.1, J1.8, J2.8, J3.8, JP8.1 (A)
/ANLGA: JP1.2 (B), JP2.2 (B), JP3.2 (B), JP4.2 (B), U1.3 (X)
/ANLGB: JP5.2 (B), JP6.2 (B), JP7.2 (B), JP8.2 (B), JP13.1 (A), U2.3 (X)
/LO_REG_LED: A1.9 (D6), J1.14, J2.14, J3.14, JP11.1 (A), U3.3
/MUX_A: A1.5 (D2), J1.10, J2.10, J3.10, U1.11 (A), U2.11 (A)
/MUX_B: A1.6 (D3), J1.11, J2.11, J3.11, U1.10 (B), U2.10 (B)
/MUX_C: A1.7 (D4), J1.12, J2.12, J3.12, U1.9 (C), U2.9 (C)
/UP_REG_LED: A1.8 (D5), J1.13, J2.13, J3.13, JP9.1 (A), U3.1
GND: A1.4 (GND), A1.29 (GND), C1.2, C2.2, C3.2, C4.2, C5.2, C6.2, C7.2, C8.2, C9.2, C10.2, C11.2, C12.2, C13.2, C14.2, J1.9, J2.9, J3.9, Q1.3 (E), RV1.3, RV2.3, RV3.3, RV4.3, RV5.3, RV6.3, RV7.3, RV8.3, RV9.3, RV10.3, RV11.3, U1.6 (Inh), U1.7 (VEE), U1.8 (VSS), U2.1 (X4), U2.2 (X6), U2.4 (X7), U2.5 (X5), U2.6 (Inh), U2.7 (VEE), U2.8 (VSS), U2.12 (X3), U3.7 (GND)
unnamed: D1.1 (K), Q1.1 (C)
unnamed: D1.2 (A), R2.1
unnamed: JP10.1 (A), U3.2
unnamed: JP9.2 (B), JP10.2 (B), JP11.2 (B), JP12.2 (B), R1.1
unnamed: JP12.1 (A), U3.4
unnamed: JP13.2 (B), RV9.2, U2.13 (X0)
unnamed: Q1.2 (B), R1.2
unnamed: RV1.2, U1.13 (X0)
unnamed: RV2.2, U1.14 (X1)
unnamed: RV3.2, U1.15 (X2)
unnamed: RV4.2, U1.12 (X3)
unnamed: RV5.2, U1.1 (X4)
unnamed: RV6.2, U1.5 (X5)
unnamed: RV7.2, U1.2 (X6)
unnamed: RV8.2, U1.4 (X7)
unnamed: RV10.2, U2.14 (X1)
unnamed: RV11.2, U2.15 (X2)

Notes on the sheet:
Reg. 2
Optional Bass
Each board controls a single LED
Reg. 1
JP9 : board 1 (most left) JP10 : board 2 JP11 : board 3 JP12 : board 4 (most right)
Active Drawbars Set
U2 only exists on the board controlling the bass drawbars. On all other boards, RV9/2 is connected to ANLGB through JP13.
There are 4 drawbars control boards. Every board controls 9 or 11 drawbars. ANLG0-7 signals go through every board, but the Arduino is present only on the last board. ANLGA and ANLGB are present on every board. They are connected to ANLG0/ANLG1 on the first board, then to ANLG2/ANLG3 on the second 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

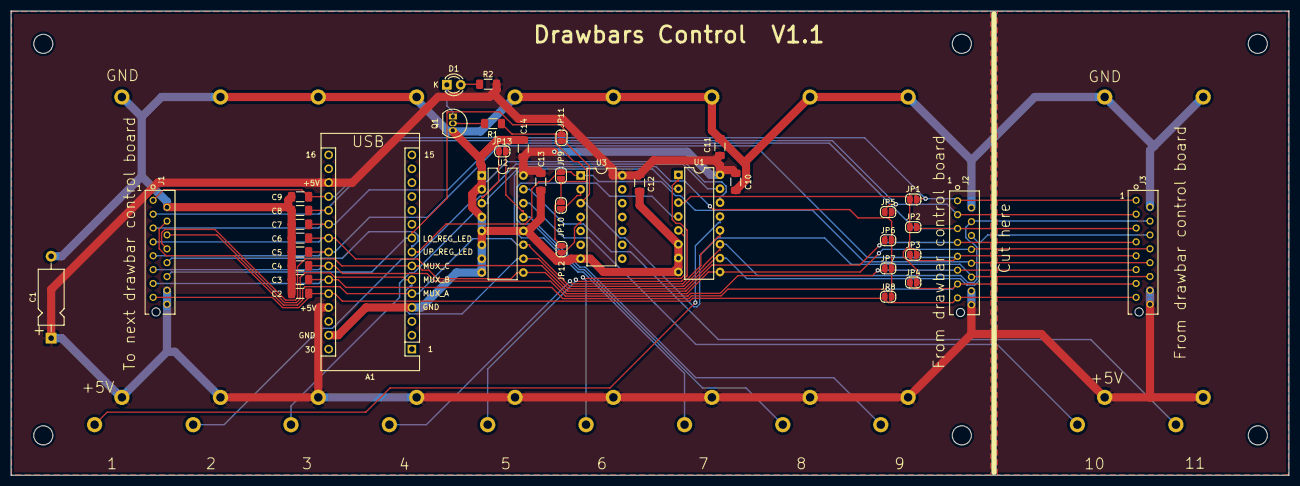
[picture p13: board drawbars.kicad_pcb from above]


Board: 2 copper layers, 234.0 x 85.0 mm, 55 parts (11 on the bottom side), 34 nets.

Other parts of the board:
REF1, REF2, REF3, REF4, REF5, REF6: MountingHole_3.5mm

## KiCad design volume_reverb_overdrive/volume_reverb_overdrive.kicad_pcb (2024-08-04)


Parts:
C1, C2, C3, C4, C5, C6: 10n; C_1206_3216Metric_Pad1.33x1.80mm_HandSolder
C7: 100n; C_1206_3216Metric_Pad1.33x1.80mm_HandSolder
C8: 10uF; CP_Radial_D5.0mm_P2.00mm
C9: 1uF; C_1206_3216Metric_Pad1.33x1.80mm_HandSolder
D1: 1N4148; D_DO-35_SOD27_P7.62mm_Horizontal
J1: Conn_02x05_Odd_Even; IDC-Header_2x05_P2.54mm_Vertical
R1: 9.1K; R_1206_3216Metric_Pad1.30x1.75mm_HandSolder
R2: 22K; R_1206_3216Metric_Pad1.30x1.75mm_HandSolder
SW1, SW2: RotaryEncoder; RotaryEncoder_Alps_EC11E-Switch_Vertical_H20mm
SW3: RotaryEncoder_Switch; RotaryEncoder_Alps_EC11E-Switch_Vertical_H20mm
U1: 74HC14; DIP-14_W7.62mm

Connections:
+3.3V: C7.1, C8.1, J1.2, R1.1, U1.14 (VCC)
/OVERDRIVE_A: C5.1, J1.4, SW3.A
/OVERDRIVE_B: C6.1, J1.6, SW3.B
/REVERB_A: C3.1, J1.7, SW2.A
/REVERB_B: C4.1, J1.8, SW2.B
/RPI_OFF: D1.2 (A), R1.2, R2.2, SW3.S1
/SHUT_DOWN: J1.1, U1.2
/VOLUME_A: C1.1, J1.3, SW1.A
/VOLUME_B: C2.1, J1.5, SW1.B
GND: C1.2, C2.2, C3.2, C4.2, C5.2, C6.2, C7.2, C8.2, C9.2, J1.9, J1.10, SW1.C, SW2.C, SW3.C, SW3.S2, U1.3, U1.5, U1.7 (GND), U1.9, U1.11, U1.13
unnamed: C9.1, D1.1 (K), R2.1, U1.1

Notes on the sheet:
GPIO 17
RPI SHUT DOWN DEBOUNCE
REVERB
GPIO 25
to GPIO 24 (RPI pin 18 / Pi-DAC+ volume control)
OVERDRIVE / RPI SHUTDOWN
to GPIO 23 (RPI pin 16 / Pi-DAC+ volume control)
VOLUME
GPIO 26
GPIO 16



Board: 2 copper layers, 150.0 x 40.1 mm, 23 parts (4 on the bottom side), 11 nets.

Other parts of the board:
REF1, REF2, REF3, REF4, REF5, REF6: MountingHole_3.2mm_M3

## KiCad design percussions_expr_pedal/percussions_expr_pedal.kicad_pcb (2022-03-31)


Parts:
C1, C2, C4, C5: 1uF; C_1206_3216Metric_Pad1.33x1.80mm_HandSolder
C3: 100n; C_1206_3216Metric_Pad1.33x1.80mm_HandSolder
D1, D2, D3, D4: 1N4148; D_DO-35_SOD27_P7.62mm_Horizontal
J1: 8-215079-4; MicroMatch_2x07_P1.27mm_Vertical
J2: Conn_01x03; PinHeader_1x03_P2.54mm_Vertical
Q1, Q2, Q3, Q4: BC547; TO-92_Inline
R1, R5, R9, R10: 7.5K; R_1206_3216Metric_Pad1.30x1.75mm_HandSolder
R2, R6, R11, R12: 18K; R_1206_3216Metric_Pad1.30x1.75mm_HandSolder
R3, R7, R13, R14: 140; R_1206_3216Metric_Pad1.30x1.75mm_HandSolder
R4, R8, R15, R16: 2.8K; R_1206_3216Metric_Pad1.30x1.75mm_HandSolder
SW1, SW2, SW3, SW4: E-SWITCH-SW_Push_LED; 5511MBLKRED
U1: 74HC14; SOIC-14_3.9x8.7mm_P1.27mm

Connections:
+5V: C3.1, J1.1, J1.2, J2.1, R1.1, R3.1, R5.1, R7.1, R9.1, R10.1, R13.1, R14.1, U1.14 (VCC)
/EXPR_PEDAL: J1.3, J2.2
/PERC_DELAY_FAST_LED: J1.7, R15.1
/PERC_DELAY_SWITCH: J1.6, U1.6
/PERC_HARMONIC_SEL_SWITCH: J1.5, U1.8
/PERC_HARMONIC_THIRD_LED: J1.4, R16.1
/PERC_ON_LED: J1.11, R4.1
/PERC_ON_OFF_SWITCH: J1.10, U1.2
/PERC_VOLUME_NORMAL_LED: J1.9, R8.1
/PERC_VOLUME_SWITCH: J1.8, U1.4
GND: C1.2, C2.2, C3.2, C4.2, C5.2, J1.12, J1.13, J1.14, J2.3, Q1.3 (E), Q2.3 (E), Q3.3 (E), Q4.3 (E), SW1.1, SW2.1, SW3.1, SW4.1, U1.7 (GND)
unnamed: C1.1, D1.1 (K), R2.1, U1.1
unnamed: C2.1, D2.1 (K), R6.1, U1.3
unnamed: C4.1, D3.1 (K), R11.1, U1.5
unnamed: C5.1, D4.1 (K), R12.1, U1.9
unnamed: D1.2 (A), R1.2, R2.2, SW1.3
unnamed: D2.2 (A), R5.2, R6.2, SW2.3
unnamed: D3.2 (A), R9.2, R11.2, SW3.3
unnamed: D4.2 (A), R10.2, R12.2, SW4.3
unnamed: Q1.1 (C), SW1.5 (K)
unnamed: Q1.2 (B), R4.2
unnamed: Q2.1 (C), SW2.5 (K)
unnamed: Q2.2 (B), R8.2
unnamed: Q3.1 (C), SW3.5 (K)
unnamed: Q3.2 (B), R15.2
unnamed: Q4.1 (C), SW4.5 (K)
unnamed: Q4.2 (B), R16.2
unnamed: R3.2, SW1.4 (A)
unnamed: R7.2, SW2.4 (A)
unnamed: R13.2, SW3.4 (A)
unnamed: R14.2, SW4.4 (A)

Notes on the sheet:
To expression pedal female jack on frame
To expression pedal female jack
To Vibrato/Chorus/Leslie Control PCB

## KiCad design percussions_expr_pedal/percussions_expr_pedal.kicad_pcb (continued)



Board: 2 copper layers, 138.8 x 71.0 mm, 40 parts (2 on the bottom side), 31 nets.

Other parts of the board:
REF1, REF2, REF3, REF4: MountingHole_3.5mm

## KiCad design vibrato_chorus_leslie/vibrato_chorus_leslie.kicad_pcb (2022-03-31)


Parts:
A1: Arduino_Nano_v3.x; Arduino_Nano
C1, C3, C6: 1uF; C_1206_3216Metric_Pad1.33x1.80mm_HandSolder
C2, C4, C5: 100n; C_1206_3216Metric_Pad1.33x1.80mm_HandSolder
D1, D2, D3: 1N4148; D_DO-35_SOD27_P7.62mm_Horizontal
J1: 7-215079-8; MicroMatch_2x04_P1.27mm_Vertical
J2: Conn_01x03; PinHeader_1x03_P2.54mm_Vertical
J3: 8-215079-4; MicroMatch_2x07_P1.27mm_Vertical
Q1, Q2, Q3: BC547; TO-92_Inline
R1, R5, R11: 7.5K; R_1206_3216Metric_Pad1.30x1.75mm_HandSolder
R2, R6, R12: 18K; R_1206_3216Metric_Pad1.30x1.75mm_HandSolder
R3, R7, R13: 140; R_1206_3216Metric_Pad1.30x1.75mm_HandSolder
R4, R8, R14: 2.8K; R_1206_3216Metric_Pad1.30x1.75mm_HandSolder
R9, R10: 68K; R_1206_3216Metric_Pad1.30x1.75mm_HandSolder
SW1, SW2, SW3: E-SWITCH-SW_Push_LED; 5511MBLKRED
U1: 74HC14; SOIC-14_3.9x8.7mm_P1.27mm

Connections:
+5V: A1.18 (AREF), A1.27 (+5V), C2.1, J2.1, J3.1, J3.2, R1.1, R3.1, R5.1, R7.1, R9.1, R11.1, R13.1, U1.14 (VCC)
/C1: A1.10 (D7), J1.2
/C2: A1.12 (D9), J1.4
/C3: A1.14 (D11), J1.6
/EXPR_PEDAL: A1.20 (A1), C4.1, J3.3
/PERC_DELAY_FAST_LED: A1.24 (A5), J3.7
/PERC_DELAY_SWITCH: A1.23 (A4), J3.6
/PERC_HARM_SEL_SWITCH: A1.22 (A3), J3.5
/PERC_HARM_THIRD_LED: A1.21 (A2), J3.4
/PERC_ON_LED: A1.15 (D12), J3.11
/PERC_SWITCH: A1.16 (D13), J3.10
/PERC_VOLUME_NORMAL_LED: A1.26 (A7), J3.9
/PERC_VOLUME_SWITCH: A1.25 (A6), J3.8
/V1: A1.9 (D6), J1.1
/V2: A1.11 (D8), J1.3
/V3: A1.13 (D10), J1.5
/VIBRATO_GREAT_ON_LED: A1.8 (D5), R14.1
/VIBRATO_GREAT_SWITCH: A1.7 (D4), U1.6
/VIBRATO_SWELL_ON_LED: A1.6 (D3), R8.1
/VIBRATO_SWELL_SWITCH: A1.5 (D2), U1.4
/VOLUME_SOFT_LED: A1.1 (D1/TX), R4.1
/VOLUME_SWITCH: A1.2 (D0/RX), U1.2
GND: A1.4 (GND), A1.29 (GND), C1.2, C2.2, C3.2, C4.2, C5.2, C6.2, J1.7, J1.8, J2.3, J3.12, J3.13, J3.14, Q1.3 (E), Q2.3 (E), Q3.3 (E), R10.2, SW1.1, SW2.1, SW3.1, U1.7 (GND), U1.9, U1.11, U1.13
unnamed: A1.19 (A0), C5.1, J2.2, R9.2, R10.1
unnamed: C1.1, D1.1 (K), R2.1, U1.1
unnamed: C3.1, D2.1 (K), R6.1, U1.3
unnamed: C6.1, D3.1 (K), R12.1, U1.5
unnamed: D1.2 (A), R1.2, R2.2, SW1.3
unnamed: D2.2 (A), R5.2, R6.2, SW2.3
unnamed: D3.2 (A), R11.2, R12.2, SW3.3
unnamed: Q1.1 (C), SW1.5 (K)
unnamed: Q1.2 (B), R4.2
unnamed: Q2.1 (C), SW2.5 (K)
unnamed: Q2.2 (B), R8.2
unnamed: Q3.1 (C), SW3.5 (K)
unnamed: Q3.2 (B), R14.2
unnamed: R3.2, SW1.4 (A)
unnamed: R7.2, SW2.4 (A)
unnamed: R13.2, SW3.4 (A)

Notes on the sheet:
To Leslie female jack on frame
To Percussions Control PCB
To Vibrato/Chorus Rotary Switch PCB



Board: 2 copper layers, 90.0 x 71.0 mm, 38 parts (4 on the bottom side), 39 nets.

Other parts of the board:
REF0, REF1, REF2, REF3: MountingHole_3.5mm

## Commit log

2022-03-31 My Hammond B3 clone KiCad projects
    KiCad PCBs projects
    [5511MBLKxxx.stp, b3_overall.kicad_pcb, b3_overall.kicad_sch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]
2022-04-13 Rev 1.1: I2C pull-ups modified
    SDA and SCL external pups (R10 and R11) discarded. Use Raspberry PI internal pups instead. Updating the PCB is not necessary.
    [rpi_extend_ctrl_panel_up.kicad_sch]
2022-04-13 Drawbars Rev 1.1
    On schematics : UP_REG_LED and LO_REG_LED signals were not routed to connectors.
    Connectors pins assignments modified.
    On PCB : Cutting line width increased. PCB width smaller for better drawbars 8 digit visibility when drawbars are pulled to max.
    [drawbars.kicad_pcb, drawbars.kicad_sch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]
2022-05-09 Rev 1.1
    I2C pull-ups discarded (use RPI I2C GPIO internal pull-ups). R9 value set to 51 Ohm.
    [rpi_extend_ctrl_panel_up.kicad_sch]
2022-05-25 Rotary encoders debounce circuit simplified
    V1.1
    [rpi_extend_ctrl_panel_up.kicad_sch]
2022-11-01 B3 clone overall diagram and volume/reverb
    Kicad overall diagram replaced with Libre Office Draw diagram.
    New volume & reverb KiCad project.
    [b3_overall.kicad_pcb, b3_overall.kicad_sch, b3_overall.sch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]
2022-11-01 Raspberry PI UP control panel discarded
    [rpi_extend_ctrl_panel_up.kicad_pcb, rpi_extend_ctrl_panel_up.kicad_sch, rpi_extend_ctrl_panel_up.sch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]
2024-08-04 Volume, reverb, overdrive and safe RPI shutdown controls
    Volume, reverb and overdrive controls are rotary encoders, now located on the same board. The overdrive rotary encoder embeds a push button to shutdown the RPI safely.
    [volume_reverb_overdrive.kicad_pcb, volume_reverb_overdrive.kicad_sch]
2024-08-04 Ignore folder volume_reverb
    [volume_reverb.kicad_pcb, volume_reverb.kicad_sch]
2024-08-04 Ignore Gerber folders
2024-08-04 A very small PCB to handle the V/C rotary switch selector
    [vibrato_chorus_rotary_switch.FCStd, vibrato_chorus_rotary_switch.kicad_pcb, vibrato_chorus_rotary_switch.kicad_sch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]
2024-08-04 Files updated to Kicad 8.0
    [5511MBLKxxx.stp, drawbars.kicad_pcb, drawbars.kicad_sch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]
2024-08-04 Info added about new volume_reverb_overdrive board
2024-11-15 New drawbars boards
    The new drawbars PCBs are not chained any more. Every new drawbar PCB is connected to the new mother board.
    [drawbars2.kicad_pcb, drawbars2.kicad_sch]
2024-11-15 The Arduino Nano Every has been discarded.
    This board is connected to the new mother board.
    [overdrive_vibrato.kicad_pcb, overdrive_vibrato.kicad_sch]
2024-11-15 New Percussions board.
    The Percussion PCB is not connected any more to the Vibrato/Chorus one; it is connected to the new mother board.
    [percussions.kicad_pcb, percussions.kicad_sch]
2024-11-15 The V/C rotary switch is now connected to the new mother board.
    [b3_mother_board.kicad_pcb, b3_mother_board.kicad_sch, keyboards_control_sub.kicad_sch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]
2025-09-19 New organ architecture with mother board
    [b3_mother_board.kicad_pcb, b3_mother_board.kicad_sch, b3_mother_board_due.kicad_pcb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]

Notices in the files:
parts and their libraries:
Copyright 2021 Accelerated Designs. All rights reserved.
